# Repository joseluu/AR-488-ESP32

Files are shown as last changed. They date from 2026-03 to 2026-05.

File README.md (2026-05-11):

# MCP-AR-488-ESP32

## Intro and goal

The idea is to have AI help me build electronics. AI needs eyes, the eyes are the oscilloscope which is used through an MCP interface.

The IEEE-488 controler is meant to expose an HTTP API which in turn is used by the MCP server.

## Build

GPIB/IEEE-488 interface board for the **Tektronix TDS784A** oscilloscope, based on an ESP32 (Heltec WiFi Kit 32) with GPIB bus transceivers. The board plugs directly onto the instrument's Centronics 24-pin GPIB connector.

This project is inspired by the [AR-488](https://github.com/Twilight-Logic/AR488) Arduino GPIB adapter, redesigned around the ESP32 for WiFi capability and higher throughput. There are ESP32 projects, such as: https://github.com/douardda/AR488-ESP32 I discovered them after having finished this one. Other projects are using the prologic serial protocol, their hardware most likely may be reflashed with the firmware here.

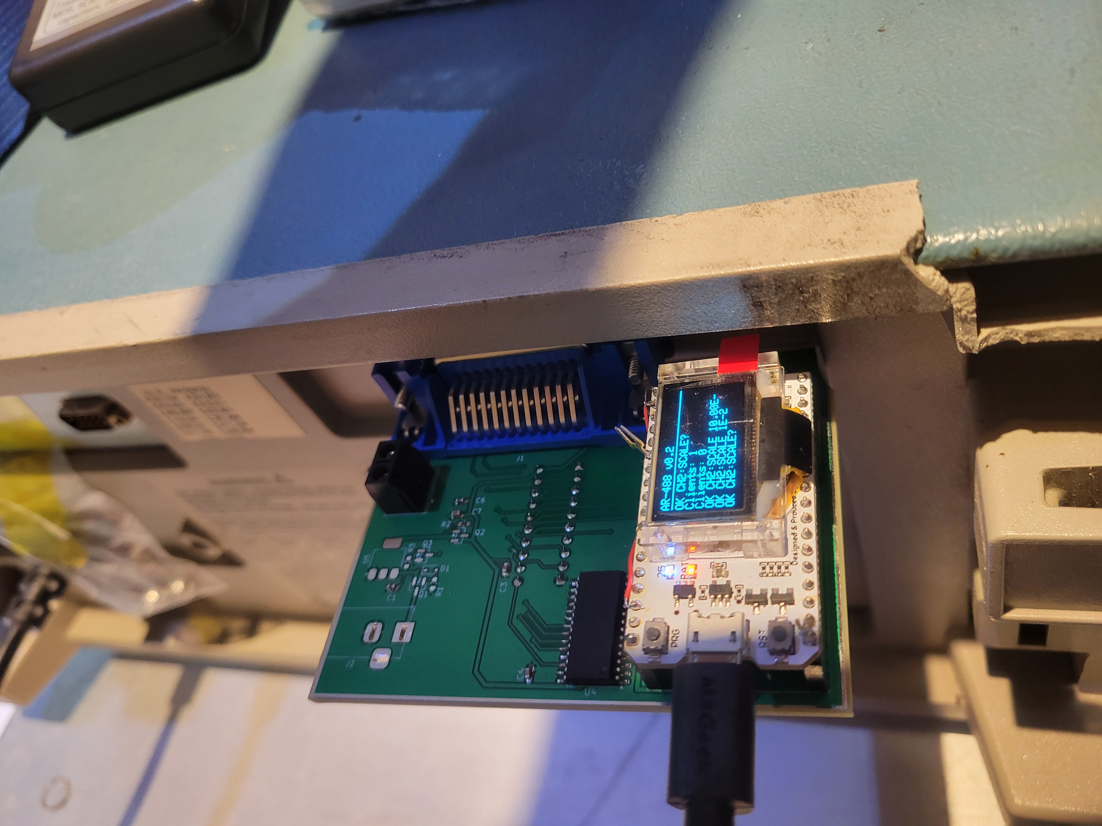
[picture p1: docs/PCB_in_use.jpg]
In use on a 784


There are a few quirks, however the PCB works, requiring some modifications (soldering):
* to supply 3.3V instead of 5.0 V to the MCP chip (because I used a V1 ESP32 board and I thought I had V2)
* add the I2C pullups
* remove 3mm from the left side to fit directly behind the TDS784
If you consider making it check the photos in the docs subdirectory. The gerber files I have used are in AR488_ESP32/Elecrow_manufacturing_v1.1.zip

The ESP32 USB can power the whole board, if you use it this way, no need to populate the barrel jack connector and power supply conditioning part (it has not been tested)

See file [IMPROVEMENTS_V2.md](IMPROVEMENTS_V2.md) for further improvements (which I may never implement myself)

## Design workflow and caveats

The PCB has been designed using AI as well, where claude is driving circuit-synth which in turn generates the kicad schematic. Routing has been handled manually.

Circuit-synth required a modification to work under Windows and git-bash (see my circuit-synth repo). Another circuit-synth
anoyance is that circuit-synth used hierachical connectors on the same sheet, this was giving warnings in the kicad rules checker.

When refreshing the circuit with circuitsynth, it uses a set of new internal identifiers, so when updating the PCB from the electrical schematic (F8) you must check the option "Re-link footprint ... from reference designators"

See file [AI_Assisted_design_workflow.md](AI_Assisted_design_workflow.md)

## Electrical architecture and implementation

See file [Electrical_Architecture.md](Electrical_Architecture.md)

The ESP32 board used is the Heltec Wifi Kit 32 (version 1), the V2 has the same pinout and can be used directly, however the V3 has different I2C pins and most likely will require adjustments to schematic and firmware.

The exposed plated area around is meant for to solder a shield to limit radiated EMI in the lab. Not tested. Shielding completely will also shield the Wifi, so at this point this is a half baked idea.

## Firmware and Software

### Hardware test
In directory hardware_test, a test firmware is available, it sends a 1ms pulse to each of the GPIB connector pins.

### Firmware
The firmware for the ESP32 implements an HTTP API json style server made available on Wifi, not the usual serial protocol.

### Host software
In firmware/test the send_gpib.py allows to exercise many features and get back entire curve data, notably in .csv format, example commands:
```
# getting curve data
uv run --with websockets python firmware/test/send_gpib.py --waveform --points 5000 --out csv --name wave --source CH2 192.168.xx.yy
# getting a screen copy in .tif format
uv run --with websockets python firmware/test/send_gpib.py 192.168.11.175 --hardcopy
```
#### downloaded CSV scope curve example
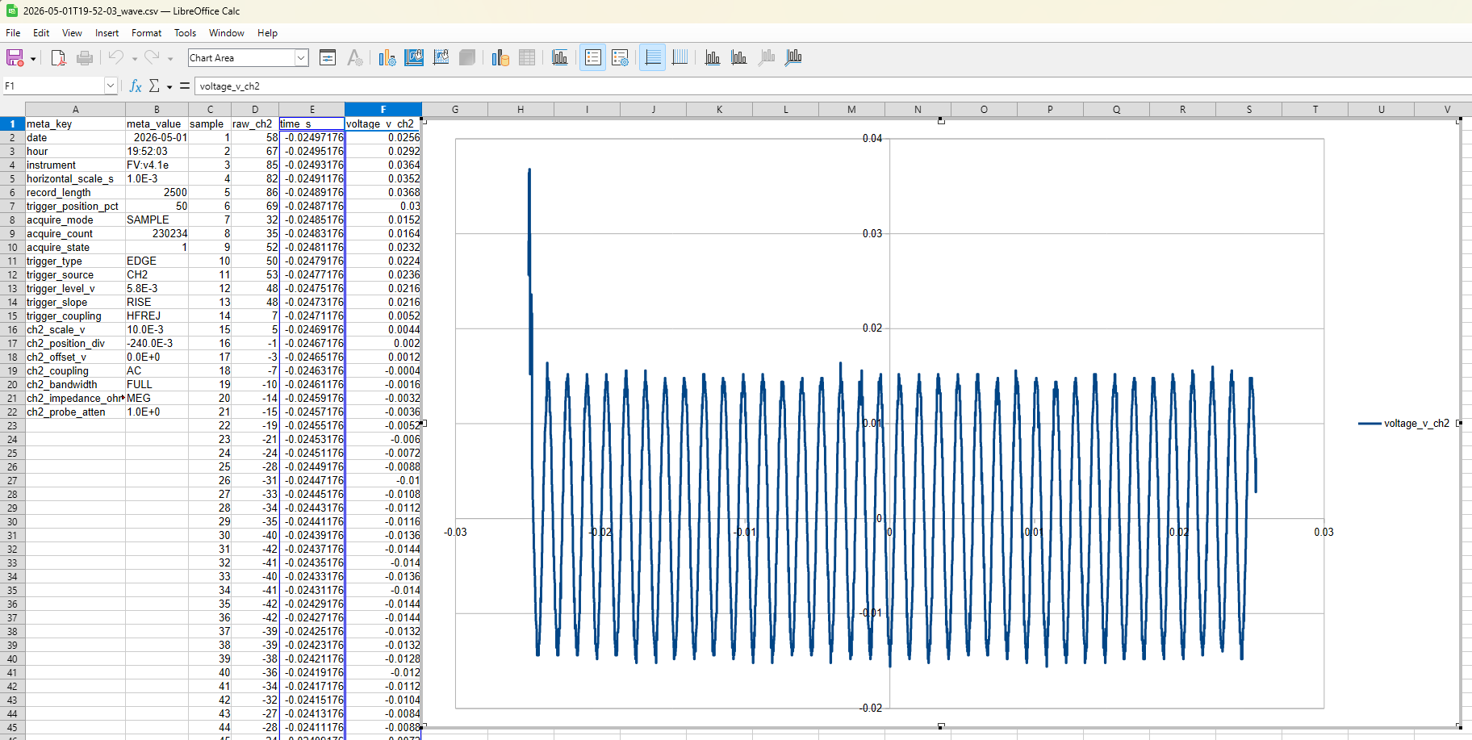
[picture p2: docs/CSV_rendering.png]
CSV being used in LibreOfficeCalc

#### Screen copy through GPIB and host software send_gpib.py
Screen copy through GPIB
#### Actual screen for comparison
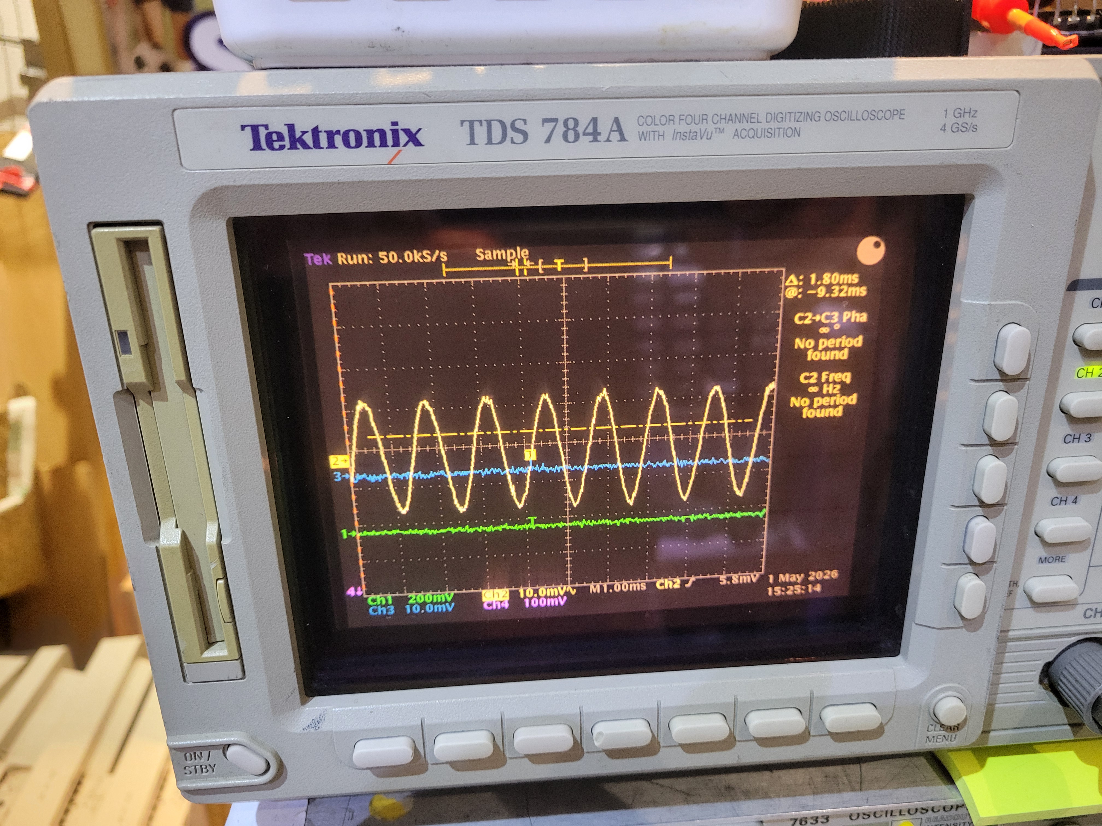
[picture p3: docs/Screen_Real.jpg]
Actual Screen


#### Host software help (-h)
```
send_gpib.py -h
usage: send_gpib.py [-h] [--addr ADDR] [--timeout TIMEOUT] [--binary] [--waveform] [--hardcopy]
                    [--hardcopy-format {TIFF,BMP,BMPCOLOR,PCX,PCXCOLOR,RLE}] [--hardcopy-layout {PORTRAIT,LANDSCAPE}]
                    [--hardcopy-palette {COLOR,MONOCHROME,INKSAVER,HARDCOPY}] [--points POINTS] [--start-index START_INDEX]
                    [--end-index END_INDEX] [--chunk-bytes CHUNK_BYTES] [--source SOURCE] [--width {1,2}] [--name NAME] [--out OUT]
                    host [command]

Send GPIB SCPI commands to a Tek scope via the AR-488-ESP32 gateway.

The ESP32 hosts a JSON-over-WebSocket bridge at ws://<host>/ws. This
script handles the protocol so an operator (or AI agent) can issue
SCPI commands and capture waveforms directly from the shell.

Invocation
----------
    send_gpib.py <ip> <scpi-command>           # auto: query if '?' else write
    send_gpib.py <ip> --binary "<scpi>"        # force binary response
    send_gpib.py <ip> --waveform [options]     # capture waveform(s)
    send_gpib.py <ip> --hardcopy [options]     # capture screen (TIFF default)
    send_gpib.py --help                         # full per-flag help

Output files
------------
Named  <ISO_8601>_<name>[_<chN>].<ext>  where:
  ISO_8601 = YYYY-MM-DDTHH-MM-SS taken at capture start (Windows-safe)
  name     = --name (default 'waveform')
  ext      = controlled by --out: 'csv', 'bin', or 'csv,bin'
  Default for --waveform is csv; other commands write nothing unless
  --out bin is given.

CSV layout
----------
    meta_key, meta_value, sample, raw_chN..., time_s, voltage_v_chN...
- Cols 1-2 hold scope state: date, hour, *IDN?, horizontal/trigger
  setup, then per-channel scale/offset/coupling/etc. Failed queries
  are silently dropped from this block.
- 'sample' is the 1-based scope record index.
- time_s/voltage_v_* are present only when WFMPRE? succeeds.

Windowed / large captures
-------------------------
TDS784A supports up to 500 000 points per record (option 1M). Use
--start-index/--end-index (1-based inclusive) to crop in the
instrument via DATA:START / DATA:STOP - only the requested range
crosses the GPIB bus. Windows larger than --chunk-bytes (default
32 KiB) are chunked transparently to fit the gateway's 64 KiB buffer.

Examples
--------
    send_gpib.py 192.168.1.42 "*IDN?"
    send_gpib.py 192.168.1.42 "CH2:SCALE 500E-3"             # 500 mV/div
    send_gpib.py 192.168.1.42 "HORIZONTAL:MAIN:SCALE?"

    # Default 5 K-pt capture from CH1 -> <stamp>_waveform.csv
    send_gpib.py 192.168.1.42 --waveform

    # Two channels, both CSV and per-channel .bin
    send_gpib.py 192.168.1.42 --waveform --source CH1,CH2 --out csv,bin

    # Full 500 K-pt record at 16-bit, custom name
    send_gpib.py 192.168.1.42 --waveform --points 500000 --width 2 --name run42

    # Sub-window 100k..105k from a 500 K record (5 K samples on the wire)
    send_gpib.py 192.168.1.42 --waveform --points 500000 \
                 --start-index 100000 --end-index 105000

    # Screen hardcopy as TIFF -> <stamp>_screen.tif
    send_gpib.py 192.168.1.42 --hardcopy

    # Hardcopy as BMP color, custom name
    send_gpib.py 192.168.1.42 --hardcopy --hardcopy-format BMPCOLOR --name run42

    # Different scope GPIB address
    send_gpib.py 192.168.1.42 --addr 5 "*IDN?"

positional arguments:
  host                  AR-488-ESP32 IP or hostname (shown on the OLED)
  command               SCPI command (omit when using --waveform)

options:
  -h, --help            show this help message and exit
  --addr ADDR           GPIB primary address (default 1)
  --timeout TIMEOUT     GPIB timeout in ms
  --binary              Force binary_query action (response returned as raw bytes)
  --waveform            Capture a waveform: configures DATA:* and runs CURVE? per channel
  --hardcopy            Capture the scope screen as an image (default TIFF). Saved to <stamp>_<name>.<ext>.
  --hardcopy-format {TIFF,BMP,BMPCOLOR,PCX,PCXCOLOR,RLE}
                        HARDCOPY:FORMAT value (default TIFF)
  --hardcopy-layout {PORTRAIT,LANDSCAPE}
                        HARDCOPY:LAYOUT value (default PORTRAIT)
  --hardcopy-palette {COLOR,MONOCHROME,INKSAVER,HARDCOPY}
                        HARDCOPY:PALETTE value (default COLOR)
  --points POINTS       Default end-index when --end-index is not given (default 5000). Set to the scope's full record length (up
                        to 500000) to grab everything.
  --start-index START_INDEX
                        First record sample to transfer, 1-based (default 1). Maps to DATA:START.
  --end-index END_INDEX
                        Last record sample to transfer, 1-based inclusive (default --points). Maps to DATA:STOP.
  --chunk-bytes CHUNK_BYTES
                        Max bytes per CURVE? response; larger windows are split into chunks transparently (default 32768; the
                        gateway caps at ~64KiB).
  --source SOURCE       Source channel(s), comma-separated (default CH1, e.g. CH1,CH2)
  --width {1,2}         Bytes per sample, 1 or 2 (default 1)
  --name NAME           Stem for output files (default 'waveform' for --waveform, 'screen' for --hardcopy, 'capture' otherwise)
  --out OUT             Output formats, comma-separated: csv, bin. Default for --waveform is 'csv'; for other commands no file is
                        written.
```

## License

MIT

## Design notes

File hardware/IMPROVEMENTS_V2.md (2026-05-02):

# Hardware Improvements & Known Issues (TODO)

This document tracks identified hardware risks and recommended revisions for the **AR-488-ESP32** project to ensure reliable operation with high-performance laboratory equipment like the **Tektronix TDS 784**.

## 0. Priority
* add pull-ups to the I2C lines !
* reduce board with by 5mm on the left side (the larger one) to fit behind the instrument

## 1. nice to have
* MCP supply must be 3.3V, the current design is for a Heltec Wifi Kit 32 (V2) try to find a design compatible with other versions
* map GPIO 5 to a test pin onboard
* Add an I2S microphone to be able to transmit voice commands to the AI
* Add a ground testing pin
* increase pin hole diameter by 0.1mm for the 488 connector pins
* The edge on the GPIB plug side can be shaved back 3mm
* Add test points on the back side, pin 24 ground and pin 1 data

## 2. Possible improvements
The following where found discussing with the AI, must be double checked before implementation

### 2.1 Logic Level Protection (Current Limiting)
* **Issue:** The SN7516x transceivers are 5V TTL devices. Their logic "High" output ($V_{OH}$) can exceed 3.6V, which is the absolute maximum rating for the ESP32 GPIOs.
* **Action:** Add **330Ω series resistors** between every ESP32 GPIO and its corresponding SN7516x pin. This protects the ESP32 from overvoltage and limits current through internal ESD protection diodes.

### 2.2 Boot Strapping Pin Conflicts
The ESP32 samples specific pins at power-up to determine its boot mode. If the GPIB bus is active, it can "back-drive" these pins and prevent the ESP32 from starting (note: this is theoretical, the ESP32 boots well when connected to the instrument)
* **GPIO 12 (MTDI):** Must be **LOW** at boot for 3.3V Flash voltage. If High, the ESP32 will boot-loop.
* **GPIO 2:** Must be **LOW** or floating at boot.
* **GPIO 0:** Must be **HIGH** for normal execution (currently safe via pull-up/button).
* **Fix:** Ensure the SN7516x **Enable (EN)** or **Direction (TE/DC)** pins are pulled to a state that keeps the transceiver in **High-Impedance (High-Z)** mode during power-on.

### 2.3 JTAG / ESP-PROG Compatibility assuming one wants to also have JTAG debugging capability
* **Issue:** The project currently utilizes **GPIO 12, 13, 14, and 15**. These are reserved for the JTAG interface used by the ESP-PROG debugger.
* **Impact:** Real-time hardware debugging is currently impossible while the GPIB interface is connected.
* **Action:** For Revision 2, consider remapping GPIB signals to non-JTAG pins, use GPIO 17, 18, 19, 23, 25, 26, 27, 2 in order to free pins for JTAG

### 2.4 Power & Decoupling
* **Action:** Tie the **GPIB Shield (Pin 12)** to the PCB digital ground to improve signal integrity during high-speed waveform transfers from the TDS 784.

### 2.5 Software-Side Initialization
* **Action:** The firmware `setup()` function must immediately set the Transceiver Control pins (TE/DC) to a "Listen" or "High-Z" state to release the strapping pins as quickly as possible after power-up.

### 2.6 Default-Safe State for SN75161B Direction Inputs
* **Issue:** `TE_CTRL` and `DC` on the SN75161B are driven by the MCP23017. After power-on reset (or any time the MCP23017 is reset or its pins are configured as inputs), the MCP23017 outputs go high-Z and these SN75161B inputs float, leaving the transceiver direction undefined and potentially driving the GPIB bus while the ESP32 is still booting.
* **Action:** Add external pull resistors (10 kΩ) on `TE_CTRL` and `DC` to define a safe default direction (Listen / device) that keeps the bus side high-Z until firmware takes over. With those pulls in place, deliberately tri-stating the MCP outputs (set `IODIRA` bits to 1) becomes a safe "release the bus" operation.

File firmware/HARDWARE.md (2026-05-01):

# AR-488-ESP32 — hardware notes for firmware developers

This document targets a developer (human or AI) porting AR-488 firmware
from another hardware platform to this board. It covers the pieces that
aren't obvious from a stock AR-488 port and that have already cost
debugging time on this design. Chip pinouts, KiCad metadata, and high
level design rationale live in `docs/TECHNICAL_INFORMATIONS.md` — read
that first if you need the chip-level reference.

## At a glance

- **MCU:** Heltec WiFi Kit 32 (ESP32). Two physical revisions exist on
  this board:
  - **V1** — ESP32-D0WDQ6, 26 MHz crystal. PIO env: `heltec_wifi_kit_32`.
  - **V2** — ESP32-PICO-D4, 40 MHz crystal. PIO env:
    `heltec_wifi_kit_32_v2`.
  Both are pin-compatible. Selecting the wrong env produces garbled
  serial because of the wrong crystal divisor.
- **GPIB transceivers:** SN75160B (data, SOIC-20W) + SN75161B (control,
  DIP-20). Both 5 V parts. Direct 3.3 V drive from ESP32 — no level
  shifters. Inputs are TTL (V_IH ~1.5 V), outputs swing 0–5 V on the MCU
  side; the ESP32's input clamp diodes tolerate this in practice but a
  series resistor (~330 Ω) is the safe-by-design fix and is on the
  hardware to-do list.
- **GPIO expander:** MCP23017 at I²C 0x20 (A0=A1=A2=GND, ~RESET tied to
  3.3 V). Powered at 3.3 V to match ESP32 logic levels on SDA/SCL.
- **OLED:** SSD1306 128×64 on internal I²C (GPIO4=SDA, GPIO15=SCL,
  GPIO16=RST). Separate from the GPIB I²C bus. Free for firmware to use
  as a status display.
- **Power:** USB Vbus (5 V) **or** barrel jack 7–12 V → AO4407A reverse
  polarity P-FET → AMS1117-5.0 LDO → 5 V rail. ESP32 module's onboard
  AMS1117-3.3 generates 3.3 V.

## GPIB signal → pin map

This is the canonical mapping. Use it verbatim; deviating breaks the PCB.

### Direct ESP32 GPIOs (data + handshake + EOI + TE_DATA + I²C)

| GPIB signal | ESP32 GPIO | Notes |
|---|---:|---|
| DIO1 | 13 | |
| DIO2 | 12 | **Strapping pin — must be LOW at boot.** |
| DIO3 | 14 | |
| DIO4 | 27 | |
| DIO5 | 26 | |
| DIO6 | 25 | Heltec onboard LED is also wired here. |
| DIO7 | 33 | |
| DIO8 | 32 | |
| DAV | 5 | Strapping pin (must be HIGH at boot — not a problem in practice, see below). |
| NRFD | 18 | |
| NDAC | 23 | |
| EOI | 19 | |
| TE_DATA | 17 | SN75160B Talk Enable. |
| I²C SDA | 21 | To MCP23017 + external pull-up. |
| I²C SCL | 22 | To MCP23017 + external pull-up. |

### MCP23017 GPIOA (slow management path)

| GPIB / control signal | MCP bit (port A) | Drives |
|---|---:|---|
| ATN | 0 | SN75161B ATN terminal pin |
| IFC | 1 | SN75161B IFC terminal pin |
| SRQ | 2 | SN75161B SRQ terminal pin |
| REN | 3 | SN75161B REN terminal pin |
| TE_CTRL | 4 | SN75161B Talk Enable |
| DC | 5 | SN75161B Direction Control |

GPIOB is unused on the board. The test firmware sets it as outputs
forced LOW; do the same to avoid floating CMOS inputs and the
shoot-through current that comes with them.

## Boot-strap caveats — read before writing `setup()`

The ESP32 samples several GPIOs at the rising edge of EN. If the GPIB
bus or the SN7516x outputs back-drive these pins to the wrong level the
chip won't boot.

| GPIO | Strapping role | This board's signal | Required at boot |
|---|---|---|---|
| 0 | Boot mode (HIGH = run) | (unused — boot button) | HIGH |
| 2 | Boot mode | (unused) | LOW or float |
| 5 | VSPI CS bootstrap | DAV | HIGH |
| 12 | Flash voltage (LOW = 3.3 V) | **DIO2** | **LOW (critical)** |
| 15 | Silent boot | (OLED, internal) | (handled by module) |

**What firmware must do at the very top of `setup()` — before anything
else, including `Serial.begin()`:**

1. `pinMode(12, OUTPUT); digitalWrite(12, LOW);` — get DIO2 off the
   strapping value path before the SN75160B has a chance to drive it.
2. Set TE_DATA (GPIO17) to a defined output. Until you do, the ESP32
   pin floats and the SN75160B's MCU-side D pins read whatever the bus
   side is doing. With TE_DATA floating-but-likely-HIGH (SN75160B Talk),
   any bus traffic ends up on the ESP32 D pins — including GPIO12.
3. Initialise I²C and write `IODIRA = 0`, then `OLATA` with TE_CTRL HIGH
   and DC LOW (controller / Talk). Until then the SN75161B's MCU-side
   pins are similarly indeterminate.

GPIO5 (DAV) being a strapping pin worked out in our favour: GPIB DAV is
unasserted = HIGH at idle, which is also the strapping requirement.
Don't drive DAV LOW before the ESP32 finishes booting.

GPIOs 6–11 are tied to internal flash and **must not** be used.
GPIOs 34–39 are input-only and unsuitable for any GPIB signal.

## Hybrid GPIO architecture — what it implies for firmware

This board is **not** a flat-GPIO design like the original AR-488 on
ATmega328P or the 32u4 fork. The 16-bit data + handshake bus is on
direct ESP32 GPIOs (per-cycle latency ~ tens of ns), but the four
management signals (ATN, IFC, SRQ, REN) and the two transceiver control
signals (TE_CTRL, DC) sit behind an I²C link to the MCP23017.

At 400 kHz I²C, one OLATA register write costs roughly **75 µs**
(start + addr + reg + data + stop). At 100 kHz it's roughly four times
that. **Do not put MCP23017 writes inside the per-byte handshake
loop** — only the direct GPIOs (DAV, NRFD, NDAC, DIO1..8, EOI) belong
there. ATN/IFC/REN flip at command boundaries, not data boundaries.

Implementation hints:

- **Cache the OLATA byte in RAM** and do a single-byte write per change
  — the test firmware shows the pattern (`g_mcpOlatA`,
  `mcpSetBitA()`).
- **Don't read-modify-write across boundaries** by doing a separate I²C
  read of GPIOA — the cached copy is authoritative because nothing else
  drives port A.
- For SRQ polling (where the board is in *device* mode and reads SRQ as
  an input), point IODIRA bit 2 to input first, read GPIOA, then put it
  back to output. Polling rate is bounded by 2× the I²C latency.

## Transceiver direction control — getting it right

The SN75161B has *two* direction inputs that decode per signal-group:

| TE  | DC  | DAV | NRFD/NDAC | EOI | ATN/IFC/REN | SRQ |
|-----|-----|---|---|---|---|---|
| 1 | 0 | drive→bus | bus→drive | drive→bus | drive→bus  | bus→drive |
| 0 | 0 | bus→drive | drive→bus | bus→drive | drive→bus  | bus→drive |
| 1 | 1 | drive→bus | bus→drive | drive→bus | bus→drive  | drive→bus |
| 0 | 1 | bus→drive | drive→bus | bus→drive | bus→drive  | drive→bus |

(See SN75161B datasheet table 1 for the authoritative version.)

In practical firmware terms:

- **DC = 0** — controller mode. ATN/IFC/REN are outputs, SRQ is an
  input. Use this for the AR-488 controller-in-charge role.
- **DC = 1** — device mode. ATN/IFC/REN are inputs, SRQ is an output.
  Use this whenever the board is acting as a GPIB device (e.g.
  asserting SRQ to request service).
- **TE = 1** — Talk for the handshake group: DAV is an output, NRFD
  and NDAC are inputs. EOI is also an output.
- **TE = 0** — Listen: DAV is an input, NRFD and NDAC are outputs.
  EOI is an input.

**Lesson learned from bring-up (don't re-derive it):**

While bringing the board up we tried flipping TE_CTRL on a per-pulse
basis to get a particular signal driven outward. Doing so produces
**coupling artefacts on neighbouring lines** — ghost edges on signals
that share the direction-decode group inside the SN75161B. The robust
pattern is:

1. Choose the bus role for the operation (controller or device).
2. Choose the direction (Talk or Listen).
3. Set TE_CTRL and DC accordingly **once** at the boundary, settle (a
   few µs is enough; the test firmware uses 1 ms as a generous margin).
4. Run the whole transaction with TE_CTRL fixed.

DC may legitimately need to flip mid-sequence (e.g. asserting SRQ as a
device while the rest of the board is in controller mode). That's fine
— it's the per-pulse TE flips that misbehave.

TE_DATA on the SN75160B is independent and only affects DIO1..8. Flip
it freely with the bus direction; there's no internal coupling between
DIO bits.

## Logic polarity (easy to get wrong)

The SN7516x parts are **non-inverting** between MCU and bus. The GPIB
bus itself is **negative-true** (a signal is *asserted* when the bus
line is LOW, due to its open-collector / wired-or nature).

Combined: writing **0** to a Talk-direction MCU pin asserts the
corresponding GPIB signal; writing **1** unasserts it. Same on the
input side — reading **0** from a Listen-direction MCU pin means the
bus signal is asserted.

The pin-test firmware (`firmware/test/`) pulses signals **HIGH** for
visibility on a scope; that's the *unasserted* level on the bus. Real
firmware should treat HIGH as the idle / negated state and assert by
driving LOW.

## I²C bus details

- **Pins:** SDA = GPIO21, SCL = GPIO22.
- **External pull-ups required.** ESP32 internal pulls (~45 kΩ) are
  too weak for reliable 400 kHz operation across PCB traces. Without
  proper pull-ups the new ESP-IDF i2c_master_ng driver returns
  `ESP_ERR_INVALID_STATE` on writes (it presents as "MCP not
  responding").
- **Speed:** 400 kHz works; 1 MHz is in the MCP23017's spec but
  hasn't been tested on this board.
- **Address:** MCP23017 at 0x20. Nothing else on this bus by default.

The internal SSD1306 OLED on the ESP32 module sits on a *different*
I²C bus (GPIO4/GPIO15) and does not interfere.

## Power notes

- USB Vbus and the barrel jack are diode-OR'd at the 5 V rail (P-FET
  reverse-polarity protection on the jack side). It's safe to have
  both connected; whichever is higher wins.
- The 3.3 V rail is generated by the Heltec module's own LDO from the
  5 V rail. Current budget for 3.3 V peripherals is small — don't add
  loads of more than ~100 mA on 3.3 V without checking.
- Decoupling: 100 nF + 22 µF on each transceiver, 100 nF on the
  MCP23017. Already on the PCB; mentioned for context if you're
  measuring noise.

## Reference firmware

The likely starting point for adaptation is the upstream AR-488:

- **Original (ATmega328P / Arduino Uno R3):**
  https://github.com/Twilight-Logic/AR488
- **32u4 fork:**
  https://github.com/artgodwin/AR488-32u4-PCB

Things in those codebases that **will not survive the port** unchanged:

- Direct port-register writes (`PORTB`, `PORTD`, `PINx`) — replace
  with `digitalWrite()` / `digitalRead()` or with ESP32's
  `GPIO.out_w1ts` / `out_w1tc` registers if you need the speed.
- Timing assumed at 16 MHz — recalibrate for 240 MHz ESP32.
- Single-port assumption (all GPIB signals on one MCU port) — not
  true here; the management signals are behind I²C.
- Pin-change interrupts — ESP32 supports them per-GPIO, not
  per-port.
- AVR sleep modes — different on ESP32; usually irrelevant for an
  always-on bus interface anyway.

A clean structural split for the port is to keep AR-488's command
parser and SCPI logic intact and replace only the bus-driver layer
with one that knows about the direct/MCP split.

## Per-pin verification

`firmware/test/` contains a stand-alone sketch that pulses every GPIB
signal in connector pin-number order. Use it to confirm the wiring
end-to-end (GPIO → transceiver → connector pin) before bringing up the
real firmware. See `firmware/test/README.md` for what it does and the
direction-control choices it embeds.

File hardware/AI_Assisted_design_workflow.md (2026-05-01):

## Design workflow with claude _ circuitsynth and kicad

The schematic is written in Python using [circuit-synth](https://github.com/circuit-synth/circuit-synth), which generates KiCad 9/10 project files. The PCB layout is done in KiCad, assisted by AI through the IPC API.

```mermaid
flowchart TD
    A["circuit-synth/main.py\nPython circuit description"] --> B["circuit-synth\nGenerates .kicad_sch, .kicad_pro, netlist"]
    B --> C["KiCad schematic editor\nReview, ERC"]
    C --> D["KiCad PCB editor\nImport netlist, place components manually"]
    D --> E["FreeRouting\nAutoroute bulk signals"]
    E --> F["AI via IPC API (MCP server)\nRefine routing, ground plane, DRC review"]
    F --> G["Final review + Gerbers\nManufacturing files"]
```

### Generating the schematic

```bash
export KICAD_SYMBOL_DIR="C:/Program Files/KiCad/9.0/share/kicad/symbols;$(pwd)/libs"
export PYTHONIOENCODING=utf-8
uv run python circuit-synth/main.py
```

The generated KiCad project is in `AR488_ESP32/`.

## Development environment setup

### Prerequisites

- **OS:** Windows 11 under **Git Bash** (Unix shell syntax throughout)
- **Python:** 3.12 via [uv](https://github.com/astral-sh/uv)
- **KiCad:** 9.0 (or 10.0 — the IPC API is the same)
- **FreeRouting:** installed as KiCad plugin or [standalone](https://github.com/freerouting/freerouting)

### Installing circuit-synth

circuit-synth is included as a **git submodule** pointing to `joseluu/circuit-synth` on the `fix/windows-utf8-file-write` branch. This branch contains fixes for Windows UTF-8 encoding issues (emoji in logs, missing `encoding="utf-8"` on `write_text()` calls) that are not yet merged upstream.

```bash
# Clone with submodule
git clone --recurse-submodules <this-repo-url>
cd AR-488-ESP32

# Or if already cloned without submodules
git submodule update --init

# Create the virtual environment and install circuit-synth in editable mode
uv sync
```

The `pyproject.toml` references circuit-synth as a local editable dependency:

```toml
[tool.uv.sources]
circuit-synth = { path = "circuit-synth", editable = true }
```

If the upstream UTF-8 fixes are eventually merged into `circuit-synth/circuit-synth`, you can switch the submodule to track the official repo instead.

### Custom KiCad libraries

The `libs/` directory contains project-specific symbols and footprints:

- `AR488_custom.kicad_sym` — SN75161BN (not in KiCad standard library), AO4407A P-FET
- `AR488_custom.pretty/Centronics_24_GPIB.kicad_mod` — Centronics 24-pin plug (2x12, 2.159mm pitch, 4.45mm row spacing, top-bottom pin numbering)
- `AR488_custom.pretty/Heltec_WiFi_Kit_32_V2.kicad_mod` — ESP32 module header (2x18, 22.86mm row spacing)

These are referenced via `KICAD_SYMBOL_DIR` at generation time (see above).

## AI-assisted PCB routing (Option C)

The PCB layout is refined using Claude via KiCad's IPC API and the Model Context Protocol (MCP).

### Setting up the MCP server

1. **Enable IPC API in KiCad:** Preferences > Plugins > Enable IPC API Server

2. **Install the MCP server** — we use [mixelpixx/KiCAD-MCP-Server](https://github.com/mixelpixx/KiCAD-MCP-Server) (Node.js + Python):

   ```bash
   # Clone next to this project
   cd ..
   git clone https://github.com/mixelpixx/KiCAD-MCP-Server.git
   cd KiCAD-MCP-Server

   # Install Node.js dependencies and build (requires Node.js 18+)
   npm install          # also runs tsc via postinstall

   # Install Python dependencies into KiCad's bundled Python (NOT system Python)
   # KiCad 9 ships its own Python 3.11 — the MCP server must use it because
   # pcbnew.pyd is compiled for that specific interpreter.
   "/c/Program Files/KiCad/9.0/bin/python.exe" -m pip install -r requirements.txt
   ```

3. **Install the IPC backend** (optional but recommended for real-time UI sync):

   ```bash
   # Install kicad-python (provides kipy — Protocol Buffers + NNG transport)
   "/c/Program Files/KiCad/9.0/bin/python.exe" -m pip install kicad-python
   ```

   The MCP server auto-detects the backend at startup:
   - **IPC backend** (`kipy` installed + KiCad running with IPC enabled): real-time UI sync, read operations work live. Write operations (routing) currently fall back to SWIG.
   - **SWIG backend** (fallback): reads/writes `.kicad_pcb` directly. Requires File > Revert in KiCad to see changes.

   SWIG is deprecated in KiCad 9 and will be removed in KiCad 10. The IPC write path is under active development.

4. **Configure Claude Code** — create a `.mcp.json` file in the **AR-488-ESP32 project directory** (already checked into the repo):

   ```json
   {
     "mcpServers": {
       "kicad": {
         "command": "<full-path-to-node>",
         "args": ["<path-to>/KiCAD-MCP-Server/dist/index.js"],
         "env": {
           "KICAD_PROJECT_DIR": "<path-to>/AR-488-ESP32/AR488_ESP32",
           "KICAD_PYTHON": "C:/Program Files/KiCad/9.0/bin/python.exe"
         }
       }
     }
   }
   ```

   Key points:
   - Use the **full path to node** (nvm-managed node isn't on PATH for spawned processes)
   - `KICAD_PYTHON` tells the server to use KiCad's bundled Python (required for pcbnew access)
   - Claude Code detects `.mcp.json` automatically when launched from the project directory

5. **Workflow:**
   - Open the PCB in KiCad's PCB editor
   - Enable IPC API: Preferences > Plugins > Enable IPC API Server
   - Place components manually (connector at board edge, decoupling caps near their ICs)
   - Manually route critical traces (power rails, high-speed signals)
   - Run FreeRouting to autoroute remaining signals (install via Plugin and Content Manager)
   - Use Claude via MCP to review DRC, optimize trace widths, add ground plane, adjust silkscreen
   - After SWIG writes: File > Revert to see changes in KiCad

### Current limitations

- The IPC API only supports the **PCB editor** (pcbnew). There is no schematic API yet — that's why we generate `.kicad_sch` files directly with circuit-synth.
- The mixelpixx MCP server uses IPC for read operations but falls back to SWIG for writes (routing, component placement). After SWIG writes, you must File > Revert in KiCad.
- Headless mode (kicad-cli as IPC server) is planned but not yet implemented.
- SWIG is deprecated in KiCad 9 and will be removed in KiCad 10 — plan to migrate to full IPC.
- Alternative: [Finerestaurant/kicad-mcp-python](https://github.com/Finerestaurant/kicad-mcp-python) is IPC-only (no SWIG) but still v0.1.

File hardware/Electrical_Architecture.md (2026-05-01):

## Electrical architecture

### Block diagram

```mermaid
flowchart TD
    PSU["7-12V DC\nBarrel Jack J2"] --> Q1["Q1 AO3401A\nP-FET RPP"]
    Q1 --> U5["U5 AMS1117-5.0\nLDO → 5V"]
    Q1 -.- D1["D1 MM3Z8V2\ngate clamp"]

    U5 --> V5[ ]:::hidden
    V5 --> U2["U2 SN75160BDW\nData transceiver\nSOIC-20, 5V"]
    V5 --> U3["U3 SN75161BN\nCtrl transceiver\nDIP-20, 5V"]
    V5 --> U4["U4 MCP23017\nI2C GPIO exp.\nSOIC-28, 3.3V"]

    U2 -- "DIO1-8 (8)\nTE_data (1)" --> U1["U1 Heltec WiFi Kit 32 V2\nESP32"]
    U3 -- "DAV, NRFD, NDAC, EOI (4)\ndirect GPIO" --> U1
    U4 -- "I2C bus\nSDA/SCL" --> U1

    U2 --> J1["J1 Centronics 24-pin\nGPIB connector"]
    U3 --> J1
    J1 --> J3["J3 Shield\nscrew terminal"]

    classDef hidden display:none;
```

### GPIB bus transceivers

The GPIB bus requires 5V signaling. Two TI transceivers handle the voltage translation:

- **SN75160BDW** (U2) — 8-bit bidirectional data bus transceiver (DIO1-DIO8). The `~PE` pin is tied to VCC to disable 3-state mode. Direction is controlled by `TE_data` from ESP32 GPIO17.

- **SN75161BN** (U3) — Control bus transceiver handling DAV, NRFD, NDAC, EOI, ATN, IFC, SRQ, REN. Direction is controlled by `TE_ctrl` and `DC`, both from the MCP23017.

No level shifters are needed: ESP32 3.3V outputs exceed the SN7516x TTL input threshold (~1.5V VIH).

### External power with reverse polarity protection

The board can be powered from a 7-12V barrel jack (J2) or from USB via the ESP32 module's 5V pin.

The barrel jack path uses an **AO3401A P-channel MOSFET** (Q1, SOT-23) for reverse polarity protection:
- Source connected to barrel jack V+
- Drain connected to AMS1117-5.0 LDO input
- Gate pulled to GND via 100k resistor (R1)
- **D1 MM3Z8V2** Zener diode (SOD-323) clamps the gate-drain voltage for ESD/spike protection

Normal operation: Vgs = 0 - Vin << 0, FET is ON with millivolt drop (~2.4mV at 200mA). Reverse polarity: Vgs >= 0, FET is OFF, circuit protected.

The **AMS1117-5.0** (U5, SOT-223) regulates down to 5V. Capacitors: 10uF input (C1), 10uF output (C2), all 0603.

Another **AO3401A P-channel MOSFET** protects the AMS1117 against current flowing back into it when the board is powered by the ESP32 (via USB)

### I2C GPIO expander — why and how

The Heltec WiFi Kit 32 V2 only exposes 16 bidirectional GPIOs (the OLED uses GPIO4/15/16). GPIB requires 18+ signals. The **MCP23017** (U4, SOIC-28) adds 16 GPIOs via I2C, of which 6 are used for slow management signals.

**Critical design choice:** The MCP23017 is powered at **3.3V**, not 5V. This is because the ESP32 I2C lines output 3.3V, and the MCP23017 at 5V requires VIH = 0.7 x 5V = 3.5V — which 3.3V cannot reliably meet. At 3.3V, the MCP23017's outputs still drive the SN75161B TTL inputs correctly (VIH ~ 1.5V).

I2C address: 0x20 (A0=A1=A2=GND). RESET tied to VCC.

### Signal routing: fast path vs slow path

The signal split between direct GPIOs and the MCP23017 is deliberate:

| Path | Signals | Latency | Used during |
|---|---|---|---|
| **Direct GPIO** (fast) | DIO1-8, DAV, NRFD, NDAC, EOI, TE_data | ~0 ns | Every byte transfer |
| **MCP23017 I2C** (slow) | ATN, IFC, SRQ, REN, TE_ctrl, DC | ~100 us | Bus mode changes only |

**Timing-constrained signals (data + handshake) are never routed through the I2C expander.** The three-wire handshake (DAV/NRFD/NDAC) and data lines (DIO1-8) must respond within microseconds during transfers. ATN, IFC, SRQ, and REN only change during bus management operations (addressing, interface clear, service request) — millisecond-level latency is acceptable.

This hybrid architecture allows the TDS784A's fast GPIB transfers (200-500 KB/s) to run at full speed while fitting within the ESP32's limited GPIO count.

## Component summary

| Ref | Component | Package | Description |
|-----|---|---|---|
| U1 | Heltec WiFi Kit 32 | 2x18 pin header | ESP32 MCU with OLED |
| U2 | SN75160BDW | SOIC-20W | GPIB data bus transceiver |
| U3 | SN75161BN | DIP-20 | GPIB control bus transceiver |
| U4 | MCP23017 | SOIC-28 | I2C GPIO expander |
| U5 | AMS1117-5.0 | SOT-223 | 5V LDO regulator |
| Q1 | AO3401A | SOT-23 | P-FET reverse polarity protection |
| Q2 | AO3401A | SOT-23 | P-FET backflow protection to AMS1117-5.0 |
| Q3 | MMBT55551L | SOT-23 | NPN power sensing |
| D1 | MM3Z8V2 | SOD-323 | 8.2V Zener gate clamp |
| J1 | Centronics 24-pin | Custom | GPIB connector |
| J2 | Barrel jack | Horizontal | 7-12V DC input |
| J3 | Screw terminal 1x2 | Phoenix PT-1.5 5mm | Shield connection |
| R1 | 100k | 0603 | Q1 gate pullup (makes it conductor) |
| R2 | 100k | 0603 | Q2 gate pulldown (makes it block) |
| R3 | 10k  | 0603 | Q3 power sensing base current limiter |
| C1 | 10uF | 0603 | LDO input cap |
| C2 | 10uF | 0603 | LDO output cap |
| C3,C4 | 100nF | 0603 | SN7516x decoupling |
| C5 | 100nF | 0603 | MCP23017 decoupling |
| C6,C7 | 22uF | 0603 | SN7516x bulk bypass |

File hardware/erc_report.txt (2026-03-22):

ERC report (2026-03-22T00:00:25+0100, Encoding UTF8)

***** Sheet /
[pin_not_connected]: Hierarchical label "SDA" in root sheet cannot be connected to non-existent parent sheet
    ; error
    @(27.94 mm, 35.56 mm): Hierarchical Label 'SDA'
[pin_not_connected]: Hierarchical label "SCL" in root sheet cannot be connected to non-existent parent sheet
    ; error
    @(27.94 mm, 38.10 mm): Hierarchical Label 'SCL'
[pin_not_connected]: Pin not connected
    ; error
    @(27.94 mm, 50.80 mm): Symbol U4 Pin 19 [INTB, Tri-state, Line]
[pin_not_connected]: Pin not connected
    ; error
    @(27.94 mm, 53.34 mm): Symbol U4 Pin 20 [INTA, Tri-state, Line]
[pin_not_connected]: Pin not connected
    ; error
    @(63.50 mm, 35.56 mm): Symbol U4 Pin 1 [GPB0, Bidirectional, Line]
[pin_not_connected]: Pin not connected
    ; error
    @(63.50 mm, 38.10 mm): Symbol U4 Pin 2 [GPB1, Bidirectional, Line]
[pin_not_connected]: Pin not connected
    ; error
    @(63.50 mm, 40.64 mm): Symbol U4 Pin 3 [GPB2, Bidirectional, Line]
[pin_not_connected]: Pin not connected
    ; error
    @(63.50 mm, 43.18 mm): Symbol U4 Pin 4 [GPB3, Bidirectional, Line]
[pin_not_connected]: Pin not connected
    ; error
    @(63.50 mm, 45.72 mm): Symbol U4 Pin 5 [GPB4, Bidirectional, Line]
[pin_not_connected]: Pin not connected
    ; error
    @(63.50 mm, 48.26 mm): Symbol U4 Pin 6 [GPB5, Bidirectional, Line]
[pin_not_connected]: Pin not connected
    ; error
    @(63.50 mm, 50.80 mm): Symbol U4 Pin 7 [GPB6, Bidirectional, Line]
[pin_not_connected]: Pin not connected
    ; error
    @(63.50 mm, 53.34 mm): Symbol U4 Pin 8 [GPB7, Output, Line]
[pin_not_connected]: Hierarchical label "ATN" in root sheet cannot be connected to non-existent parent sheet
    ; error
    @(63.50 mm, 58.42 mm): Hierarchical Label 'ATN'
[pin_not_connected]: Hierarchical label "IFC" in root sheet cannot be connected to non-existent parent sheet
    ; error
    @(63.50 mm, 60.96 mm): Hierarchical Label 'IFC'
[pin_not_connected]: Hierarchical label "SRQ" in root sheet cannot be connected to non-existent parent sheet
    ; error
    @(63.50 mm, 63.50 mm): Hierarchical Label 'SRQ'
[pin_not_connected]: Hierarchical label "REN" in root sheet cannot be connected to non-existent parent sheet
    ; error
    @(63.50 mm, 66.04 mm): Hierarchical Label 'REN'
[pin_not_connected]: Hierarchical label "TE_CTRL" in root sheet cannot be connected to non-existent parent sheet
    ; error
    @(86.36 mm, 35.56 mm): Hierarchical Label 'TE_CTRL'
[pin_not_connected]: Hierarchical label "TE_CTRL" in root sheet cannot be connected to non-existent parent sheet
    ; error
    @(86.36 mm, 35.56 mm): Hierarchical Label 'TE_CTRL'
[pin_not_connected]: Hierarchical label "TE_CTRL" in root sheet cannot be connected to non-existent parent sheet
    ; error
    @(63.50 mm, 68.58 mm): Hierarchical Label 'TE_CTRL'
[pin_not_connected]: Hierarchical label "DC" in root sheet cannot be connected to non-existent parent sheet
    ; error
    @(86.36 mm, 38.10 mm): Hierarchical Label 'DC'
[pin_not_connected]: Hierarchical label "DC" in root sheet cannot be connected to non-existent parent sheet
    ; error
    @(86.36 mm, 38.10 mm): Hierarchical Label 'DC'
[pin_not_connected]: Hierarchical label "DC" in root sheet cannot be connected to non-existent parent sheet
    ; error
    @(63.50 mm, 71.12 mm): Hierarchical Label 'DC'
[pin_not_connected]: Hierarchical label "REN" in root sheet cannot be connected to non-existent parent sheet
    ; error
    @(86.36 mm, 43.18 mm): Hierarchical Label 'REN'
[pin_not_connected]: Hierarchical label "REN" in root sheet cannot be connected to non-existent parent sheet
    ; error
    @(86.36 mm, 43.18 mm): Hierarchical Label 'REN'
[pin_not_connected]: Pin not connected
    ; error
    @(63.50 mm, 73.66 mm): Symbol U4 Pin 27 [GPA6, Bidirectional, Line]
[pin_not_connected]: Hierarchical label "IFC" in root sheet cannot be connected to non-existent parent sheet
    ; error
    @(86.36 mm, 45.72 mm): Hierarchical Label 'IFC'
[pin_not_connected]: Hierarchical label "IFC" in root sheet cannot be connected to non-existent parent sheet
    ; error
    @(86.36 mm, 45.72 mm): Hierarchical Label 'IFC'
[pin_not_connected]: Hierarchical label "NDAC" in root sheet cannot be connected to non-existent parent sheet
    ; error
    @(86.36 mm, 48.26 mm): Hierarchical Label 'NDAC'
[pin_not_connected]: Hierarchical label "NDAC" in root sheet cannot be connected to non-existent parent sheet
    ; error
    @(86.36 mm, 48.26 mm): Hierarchical Label 'NDAC'
[pin_not_connected]: Pin not connected
    ; error
    @(63.50 mm, 76.20 mm): Symbol U4 Pin 28 [GPA7, Output, Line]
[pin_not_connected]: Hierarchical label "NRFD" in root sheet cannot be connected to non-existent parent sheet
    ; error
    @(86.36 mm, 50.80 mm): Hierarchical Label 'NRFD'
[pin_not_connected]: Hierarchical label "NRFD" in root sheet cannot be connected to non-existent parent sheet
    ; error
    @(86.36 mm, 50.80 mm): Hierarchical Label 'NRFD'
[pin_not_connected]: Hierarchical label "DAV" in root sheet cannot be connected to non-existent parent sheet
    ; error
    @(86.36 mm, 53.34 mm): Hierarchical Label 'DAV'
[pin_not_connected]: Hierarchical label "DAV" in root sheet cannot be connected to non-existent parent sheet
    ; error
    @(86.36 mm, 53.34 mm): Hierarchical Label 'DAV'
[pin_not_connected]: Hierarchical label "EOI" in root sheet cannot be connected to non-existent parent sheet
    ; error
    @(86.36 mm, 55.88 mm): Hierarchical Label 'EOI'
[pin_not_connected]: Hierarchical label "EOI" in root sheet cannot be connected to non-existent parent sheet
    ; error
    @(86.36 mm, 55.88 mm): Hierarchical Label 'EOI'
[pin_not_connected]: Hierarchical label "ATN" in root sheet cannot be connected to non-existent parent sheet
    ; error
    @(86.36 mm, 58.42 mm): Hierarchical Label 'ATN'
[pin_not_connected]: Hierarchical label "ATN" in root sheet cannot be connected to non-existent parent sheet
    ; error
    @(86.36 mm, 58.42 mm): Hierarchical Label 'ATN'
[pin_not_connected]: Hierarchical label "SRQ" in root sheet cannot be connected to non-existent parent sheet
    ; error
    @(86.36 mm, 60.96 mm): Hierarchical Label 'SRQ'
[pin_not_connected]: Hierarchical label "SRQ" in root sheet cannot be connected to non-existent parent sheet
    ; error
    @(86.36 mm, 60.96 mm): Hierarchical Label 'SRQ'
[pin_not_connected]: Hierarchical label "REN_B" in root sheet cannot be connected to non-existent parent sheet
    ; error
    @(111.76 mm, 43.18 mm): Hierarchical Label 'REN_B'
[pin_not_connected]: Hierarchical label "REN_B" in root sheet cannot be connected to non-existent parent sheet
    ; error
    @(111.76 mm, 43.18 mm): Hierarchical Label 'REN_B'
[pin_not_connected]: Hierarchical label "IFC_B" in root sheet cannot be connected to non-existent parent sheet
    ; error
    @(111.76 mm, 45.72 mm): Hierarchical Label 'IFC_B'
[pin_not_connected]: Hierarchical label "IFC_B" in root sheet cannot be connected to non-existent parent sheet
    ; error
    @(111.76 mm, 45.72 mm): Hierarchical Label 'IFC_B'
[pin_not_connected]: Hierarchical label "NDAC_B" in root sheet cannot be connected to non-existent parent sheet
    ; error
    @(111.76 mm, 48.26 mm): Hierarchical Label 'NDAC_B'
[pin_not_connected]: Hierarchical label "NDAC_B" in root sheet cannot be connected to non-existent parent sheet
    ; error
    @(111.76 mm, 48.26 mm): Hierarchical Label 'NDAC_B'
[pin_not_connected]: Hierarchical label "NRFD_B" in root sheet cannot be connected to non-existent parent sheet
    ; error
    @(111.76 mm, 50.80 mm): Hierarchical Label 'NRFD_B'
[pin_not_connected]: Hierarchical label "NRFD_B" in root sheet cannot be connected to non-existent parent sheet
    ; error
    @(111.76 mm, 50.80 mm): Hierarchical Label 'NRFD_B'
[pin_not_connected]: Hierarchical label "DAV_B" in root sheet cannot be connected to non-existent parent sheet
    ; error
    @(111.76 mm, 53.34 mm): Hierarchical Label 'DAV_B'
[pin_not_connected]: Hierarchical label "DAV_B" in root sheet cannot be connected to non-existent parent sheet
    ; error
    @(111.76 mm, 53.34 mm): Hierarchical Label 'DAV_B'
[pin_not_connected]: Hierarchical label "EOI_B" in root sheet cannot be connected to non-existent parent sheet
    ; error
    @(111.76 mm, 55.88 mm): Hierarchical Label 'EOI_B'
[pin_not_connected]: Hierarchical label "EOI_B" in root sheet cannot be connected to non-existent parent sheet
    ; error
    @(111.76 mm, 55.88 mm): Hierarchical Label 'EOI_B'
[pin_not_connected]: Hierarchical label "ATN_B" in root sheet cannot be connected to non-existent parent sheet
    ; error
    @(111.76 mm, 58.42 mm): Hierarchical Label 'ATN_B'
[pin_not_connected]: Hierarchical label "ATN_B" in root sheet cannot be connected to non-existent parent sheet
    ; error
    @(111.76 mm, 58.42 mm): Hierarchical Label 'ATN_B'
[pin_not_connected]: Hierarchical label "SRQ_B" in root sheet cannot be connected to non-existent parent sheet
    ; error
    @(111.76 mm, 60.96 mm): Hierarchical Label 'SRQ_B'
[pin_not_connected]: Hierarchical label "SRQ_B" in root sheet cannot be connected to non-existent parent sheet
    ; error
    @(111.76 mm, 60.96 mm): Hierarchical Label 'SRQ_B'
[pin_not_connected]: Hierarchical label "LDO_IN" in root sheet cannot be connected to non-existent parent sheet
    ; error
    @(35.56 mm, 134.62 mm): Hierarchical Label 'LDO_IN'
[pin_not_connected]: Hierarchical label "LDO_IN" in root sheet cannot be connected to non-existent parent sheet
    ; error
    @(35.56 mm, 134.62 mm): Hierarchical Label 'LDO_IN'
[pin_not_connected]: Hierarchical label "DIO1" in root sheet cannot be connected to non-existent parent sheet
    ; error
    @(137.16 mm, 35.56 mm): Hierarchical Label 'DIO1'
[pin_not_connected]: Hierarchical label "DIO2" in root sheet cannot be connected to non-existent parent sheet
    ; error
    @(137.16 mm, 38.10 mm): Hierarchical Label 'DIO2'
[pin_not_connected]: Hierarchical label "Q1_GATE" in root sheet cannot be connected to non-existent parent sheet
    ; error
    @(27.94 mm, 139.70 mm): Hierarchical Label 'Q1_GATE'
[pin_not_connected]: Hierarchical label "Q1_GATE" in root sheet cannot be connected to non-existent parent sheet
    ; error
    @(27.94 mm, 139.70 mm): Hierarchical Label 'Q1_GATE'
[pin_not_connected]: Hierarchical label "DIO3" in root sheet cannot be connected to non-existent parent sheet
    ; error
    @(137.16 mm, 40.64 mm): Hierarchical Label 'DIO3'
[pin_not_connected]: Hierarchical label "DIO4" in root sheet cannot be connected to non-existent parent sheet
    ; error
    @(137.16 mm, 43.18 mm): Hierarchical Label 'DIO4'
[pin_not_connected]: Hierarchical label "DIO5" in root sheet cannot be connected to non-existent parent sheet
    ; error
    @(137.16 mm, 45.72 mm): Hierarchical Label 'DIO5'
[pin_not_connected]: Hierarchical label "DIO6" in root sheet cannot be connected to non-existent parent sheet
    ; error
    @(137.16 mm, 48.26 mm): Hierarchical Label 'DIO6'
[pin_not_connected]: Pin not connected
    ; error
    @(71.12 mm, 127.00 mm): Symbol J2 Pin 1 [Passive, Line]
[pin_not_connected]: Hierarchical label "DIO7" in root sheet cannot be connected to non-existent parent sheet
    ; error
    @(137.16 mm, 50.80 mm): Hierarchical Label 'DIO7'
[pin_not_connected]: Hierarchical label "DIO8" in root sheet cannot be connected to non-existent parent sheet
    ; error
    @(137.16 mm, 53.34 mm): Hierarchical Label 'DIO8'
[pin_not_connected]: Pin not connected
    ; error
    @(35.56 mm, 144.78 mm): Symbol Q1 Pin 1 [S, Passive, Line]
[pin_not_connected]: Hierarchical label "DIO1_B" in root sheet cannot be connected to non-existent parent sheet
    ; error
    @(157.48 mm, 35.56 mm): Hierarchical Label 'DIO1_B'
[pin_not_connected]: Hierarchical label "DIO2_B" in root sheet cannot be connected to non-existent parent sheet
    ; error
    @(157.48 mm, 38.10 mm): Hierarchical Label 'DIO2_B'
[pin_not_connected]: Hierarchical label "Q1_GATE" in root sheet cannot be connected to non-existent parent sheet
    ; error
    @(91.44 mm, 135.89 mm): Hierarchical Label 'Q1_GATE'
[pin_not_connected]: Hierarchical label "LDO_IN" in root sheet cannot be connected to non-existent parent sheet
    ; error
    @(116.84 mm, 133.35 mm): Hierarchical Label 'LDO_IN'
[power_pin_not_driven]: Input Power pin not driven by any Output Power pins
    ; error
    @(180.34 mm, 27.94 mm): Symbol #PWR028 Pin 1 [Power input, Line]
[pin_not_connected]: Pin not connected
    ; error
    @(180.34 mm, 30.48 mm): Symbol U1 Pin 5 [Pin_5, Passive, Line]
[pin_not_connected]: Pin not connected
    ; error
    @(180.34 mm, 33.02 mm): Symbol U1 Pin 7 [Pin_7, Passive, Line]
[pin_not_connected]: Hierarchical label "DIO1" in root sheet cannot be connected to non-existent parent sheet
    ; error
    @(180.34 mm, 35.56 mm): Hierarchical Label 'DIO1'
[pin_not_connected]: Hierarchical label "DIO2" in root sheet cannot be connected to non-existent parent sheet
    ; error
    @(180.34 mm, 38.10 mm): Hierarchical Label 'DIO2'
[pin_not_connected]: Hierarchical label "DIO3" in root sheet cannot be connected to non-existent parent sheet
    ; error
    @(180.34 mm, 40.64 mm): Hierarchical Label 'DIO3'
[pin_not_connected]: Hierarchical label "DIO4" in root sheet cannot be connected to non-existent parent sheet
    ; error
    @(180.34 mm, 43.18 mm): Hierarchical Label 'DIO4'
[pin_not_connected]: Hierarchical label "DIO5" in root sheet cannot be connected to non-existent parent sheet
    ; error
    @(180.34 mm, 45.72 mm): Hierarchical Label 'DIO5'
[pin_not_connected]: Hierarchical label "DIO6" in root sheet cannot be connected to non-existent parent sheet
    ; error
    @(180.34 mm, 48.26 mm): Hierarchical Label 'DIO6'
[pin_not_connected]: Hierarchical label "DIO7" in root sheet cannot be connected to non-existent parent sheet
    ; error
    @(180.34 mm, 50.80 mm): Hierarchical Label 'DIO7'
[pin_not_connected]: Hierarchical label "DIO8" in root sheet cannot be connected to non-existent parent sheet
    ; error
    @(180.34 mm, 53.34 mm): Hierarchical Label 'DIO8'
[pin_not_connected]: Pin not connected
    ; error
    @(180.34 mm, 55.88 mm): Symbol U1 Pin 25 [Pin_25, Passive, Line]
[pin_not_connected]: Pin not connected
    ; error
    @(180.34 mm, 58.42 mm): Symbol U1 Pin 27 [Pin_27, Passive, Line]
[pin_not_connected]: Pin not connected
    ; error
    @(180.34 mm, 60.96 mm): Symbol U1 Pin 29 [Pin_29, Passive, Line]
[pin_not_connected]: Pin not connected
    ; error
    @(180.34 mm, 63.50 mm): Symbol U1 Pin 31 [Pin_31, Passive, Line]
[pin_not_connected]: Pin not connected
    ; error
    @(180.34 mm, 66.04 mm): Symbol U1 Pin 33 [Pin_33, Passive, Line]
[pin_not_connected]: Pin not connected
    ; error
    @(180.34 mm, 68.58 mm): Symbol U1 Pin 35 [Pin_35, Passive, Line]
[pin_not_connected]: Pin not connected
    ; error
    @(193.04 mm, 30.48 mm): Symbol U1 Pin 6 [Pin_6, Passive, Line]
[pin_not_connected]: Pin not connected
    ; error
    @(193.04 mm, 33.02 mm): Symbol U1 Pin 8 [Pin_8, Passive, Line]
[pin_not_connected]: Pin not connected
    ; error
    @(193.04 mm, 35.56 mm): Symbol U1 Pin 10 [Pin_10, Passive, Line]
[pin_not_connected]: Pin not connected
    ; error
    @(193.04 mm, 38.10 mm): Symbol U1 Pin 12 [Pin_12, Passive, Line]
[pin_not_connected]: Pin not connected
    ; error
    @(193.04 mm, 40.64 mm): Symbol U1 Pin 14 [Pin_14, Passive, Line]
[pin_not_connected]: Pin not connected
    ; error
    @(193.04 mm, 43.18 mm): Symbol U1 Pin 16 [Pin_16, Passive, Line]
[pin_not_connected]: Pin not connected
    ; error
    @(193.04 mm, 45.72 mm): Symbol U1 Pin 18 [Pin_18, Passive, Line]
[pin_not_connected]: Pin not connected
    ; error
    @(193.04 mm, 48.26 mm): Symbol U1 Pin 20 [Pin_20, Passive, Line]
[pin_not_connected]: Pin not connected
    ; error
    @(193.04 mm, 50.80 mm): Symbol U1 Pin 22 [Pin_22, Passive, Line]
[pin_not_connected]: Hierarchical label "TE_DATA" in root sheet cannot be connected to non-existent parent sheet
    ; error
    @(193.04 mm, 53.34 mm): Hierarchical Label 'TE_DATA'
[pin_not_connected]: Hierarchical label "DAV" in root sheet cannot be connected to non-existent parent sheet
    ; error
    @(193.04 mm, 55.88 mm): Hierarchical Label 'DAV'
[pin_not_connected]: Hierarchical label "NRFD" in root sheet cannot be connected to non-existent parent sheet
    ; error
    @(193.04 mm, 58.42 mm): Hierarchical Label 'NRFD'
[pin_not_connected]: Hierarchical label "NDAC" in root sheet cannot be connected to non-existent parent sheet
    ; error
    @(193.04 mm, 60.96 mm): Hierarchical Label 'NDAC'
[pin_not_connected]: Hierarchical label "EOI" in root sheet cannot be connected to non-existent parent sheet
    ; error
    @(193.04 mm, 63.50 mm): Hierarchical Label 'EOI'
[pin_not_connected]: Hierarchical label "SCL" in root sheet cannot be connected to non-existent parent sheet
    ; error
    @(193.04 mm, 66.04 mm): Hierarchical Label 'SCL'
[pin_not_connected]: Hierarchical label "SDA" in root sheet cannot be connected to non-existent parent sheet
    ; error
    @(193.04 mm, 68.58 mm): Hierarchical Label 'SDA'
[pin_not_connected]: Hierarchical label "DIO1_B" in root sheet cannot be connected to non-existent parent sheet
    ; error
    @(215.90 mm, 25.40 mm): Hierarchical Label 'DIO1_B'
[pin_not_connected]: Hierarchical label "DIO2_B" in root sheet cannot be connected to non-existent parent sheet
    ; error
    @(215.90 mm, 27.94 mm): Hierarchical Label 'DIO2_B'
[pin_not_connected]: Hierarchical label "DIO3_B" in root sheet cannot be connected to non-existent parent sheet
    ; error
    @(215.90 mm, 30.48 mm): Hierarchical Label 'DIO3_B'
[pin_not_connected]: Hierarchical label "DIO4_B" in root sheet cannot be connected to non-existent parent sheet
    ; error
    @(215.90 mm, 33.02 mm): Hierarchical Label 'DIO4_B'
[pin_not_connected]: Hierarchical label "EOI_B" in root sheet cannot be connected to non-existent parent sheet
    ; error
    @(215.90 mm, 35.56 mm): Hierarchical Label 'EOI_B'
[pin_not_connected]: Hierarchical label "DAV_B" in root sheet cannot be connected to non-existent parent sheet
    ; error
    @(215.90 mm, 38.10 mm): Hierarchical Label 'DAV_B'
[pin_not_connected]: Hierarchical label "NRFD_B" in root sheet cannot be connected to non-existent parent sheet
    ; error
    @(215.90 mm, 40.64 mm): Hierarchical Label 'NRFD_B'
[pin_not_connected]: Hierarchical label "NDAC_B" in root sheet cannot be connected to non-existent parent sheet
    ; error
    @(215.90 mm, 43.18 mm): Hierarchical Label 'NDAC_B'
[pin_not_connected]: Hierarchical label "IFC_B" in root sheet cannot be connected to non-existent parent sheet
    ; error
    @(215.90 mm, 45.72 mm): Hierarchical Label 'IFC_B'
[pin_not_connected]: Hierarchical label "SRQ_B" in root sheet cannot be connected to non-existent parent sheet
    ; error
    @(215.90 mm, 48.26 mm): Hierarchical Label 'SRQ_B'
[pin_not_connected]: Hierarchical label "ATN_B" in root sheet cannot be connected to non-existent parent sheet
    ; error
    @(215.90 mm, 50.80 mm): Hierarchical Label 'ATN_B'
[power_pin_not_driven]: Input Power pin not driven by any Output Power pins
    ; error
    @(215.90 mm, 53.34 mm): Symbol #PWR001 Pin 1 [Power input, Line]
[pin_not_connected]: Hierarchical label "DIO5_B" in root sheet cannot be connected to non-existent parent sheet
    ; error
    @(228.60 mm, 25.40 mm): Hierarchical Label 'DIO5_B'
[pin_not_connected]: Hierarchical label "DIO6_B" in root sheet cannot be connected to non-existent parent sheet
    ; error
    @(228.60 mm, 27.94 mm): Hierarchical Label 'DIO6_B'
[pin_not_connected]: Hierarchical label "DIO7_B" in root sheet cannot be connected to non-existent parent sheet
    ; error
    @(228.60 mm, 30.48 mm): Hierarchical Label 'DIO7_B'
[pin_not_connected]: Hierarchical label "DIO8_B" in root sheet cannot be connected to non-existent parent sheet
    ; error
    @(228.60 mm, 33.02 mm): Hierarchical Label 'DIO8_B'
[pin_not_connected]: Hierarchical label "REN_B" in root sheet cannot be connected to non-existent parent sheet
    ; error
    @(228.60 mm, 35.56 mm): Hierarchical Label 'REN_B'
[pin_not_connected]: Hierarchical label "LDO_IN" in root sheet cannot be connected to non-existent parent sheet
    ; error
    @(251.46 mm, 30.48 mm): Hierarchical Label 'LDO_IN'
[power_pin_not_driven]: Input Power pin not driven by any Output Power pins
    ; error
    @(251.46 mm, 30.48 mm): Symbol U5 Pin 3 [VI, Power input, Line]
[lib_symbol_mismatch]: Symbol 'MCP23017_SO' doesn't match copy in library 'Interface_Expansion'
    ; warning
    @(45.72 mm, 55.88 mm): Symbol U4 [MCP23017_SO]
[lib_symbol_issues]: The current configuration does not include the symbol library 'AR488_custom'
    ; warning
    @(99.06 mm, 53.34 mm): Symbol U3 [SN75161BN]
[lib_symbol_issues]: The current configuration does not include the symbol library 'AR488_custom'
    ; warning
    @(33.02 mm, 139.70 mm): Symbol Q1 [AO4407A]
[footprint_link_issues]: The current configuration does not include the footprint library 'AR488_custom'.
    ; warning
    @(185.42 mm, 45.72 mm): Symbol U1 [Conn_02x18_Odd_Even]
[footprint_link_issues]: The current configuration does not include the footprint library 'AR488_custom'.
    ; warning
    @(220.98 mm, 38.10 mm): Symbol J1 [Conn_02x12_Odd_Even]

 ** ERC messages: 131  Errors 126  Warnings 5

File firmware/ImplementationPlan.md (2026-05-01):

This plan focuses on building a **Dual-Core "Gateway"** firmware. It treats the GPIB bus as a protected resource, allowing you to run a high-performance JSON/MCP interface today while leaving a "slot" open for a Legacy Prologix-style task later.

### `Implementation\\\_Plan.md`

# Project: Modern AI-GPIB Gateway (ESP32 to Tektronix 784)

## Overview

A streamlined ESP32 firmware designed for AI-driven laboratory automation. It utilizes a non-blocking WebSocket/JSON interface for modern agents (via MCP) and provides a thread-safe path for legacy IEEE-488.2 compatibility.

Hardware is the Heltec ESP32 Wifi Kit V1 with OLED

## Phase 1: The Hardware Abstraction Layer (HAL)

**Goal:** Create a thread-safe C++ Class using direct register access.

### 1.1 `GpibBus` Class Definition

- **Encapsulation:** Protect GPIB pins using a FreeRTOS Mutex (`SemaphoreHandle\\\_t`).

- **Register Mapping:** Define macros for GPIO Port A/B writes for the 8-bit data bus.

- **Handshake Logic:** Implement `write\\\_byte` and `read\\\_byte` using the 3-wire handshake (DAV, NRFD, NDAC).

### 1.2 Validation (Test 1)

- **Flash firmware.**

- **Detect GPIB connection and indicate detection on the OLED**

- **Test:** send `\\\*IDN?` query to the Tek 784.

- **Success Criteria:** The scope returns `"TEKTRONIX,784..."` without timing out.

- Display return value on the OLED

## Phase 2: The Modern Communication Core

**Goal:** Establish a JSON-over-WebSocket transport on Core 0.

implementation note: use the file network\_creds.h to connect to local Wifi AP

### 2.1 Async WebSocket Server

- Use `ESPAsyncWebServer` to handle incoming JSON frames.

- **Protocol:**

- JSON

`\\\{`

- `  "request\\\_id": "123",`

- ` "action": "query",`

- `  "command": "CH1:SCALE?"`

- `\\\}`

```
  
\#\#\# 2.2 Command Dispatcher  
  
- Parse JSON using \`ArduinoJson\`.  
  
- Acquire the \`GpibBus\` mutex.  
  
- Execute the command on the bus and capture the response.  
  
- Return a JSON response frame.  
  
\#\#\# 2.3 Validation (Test 2)  
  
- \*\*Flash firmware.\*\*  
  
- \*\*Report IP address on OLED\*\*  
  
- \*\*Test:\*\*  Make a Python script to send a WebSocket JSON request for the scope's horizontal scale.  
  
- \*\*Do some communication traces on the OLED\*\*  
  
- \*\*Success Criteria:\*\* Valid JSON received containing the numeric scale value.  

\#\# Phase 3: High-Bandwidth Data Handling  
  
\*\*Goal:\*\* Efficiently handle large waveform captures (CURVe? data).  
  
\#\#\# 3.1 Binary Pass-through  
  
- Detect when a command expects a large binary payload (e.g., \`CURV?\`).  
  
- Implement a "Raw Mode" where the HAL streams bytes directly from the bus to the WebSocket buffer to avoid memory fragmentation on the ESP32.  
  
\#\#\# 3.2 Validation (Test 3)  
  
- \*\*Test:\*\* Request a 5,000-point waveform capture.  
  
- \*\*Success Criteria:\*\* Data is received in under 500ms and matches the visual representation on the scope.  

\#\# Phase 4: MCP Integration (Local Machine)  
  
\*\*Goal:\*\* Bridge the AI to the ESP32.  
  
\#\#\# 4.1 Python MCP Server  
  
- Implement an MCP server using the Python SDK.  
  
- Define Tools: \`get\\\_waveform\`, \`set\\\_vertical\\\_scale\`, \`auto\\\_setup\`.  
  
- The server maintains a persistent WebSocket connection to the ESP32.  
  
\#\#\# 4.2 Validation (Test 4)  
  
- \*\*Test:\*\* Prompt the AI: \*"Analyze the signal on Channel 1 and tell me if the rise time is within TTL specs."\*  
  
- \*\*Success Criteria:\*\* AI triggers the tools, receives the data, and provides a correct engineering analysis.  

\#\# Phase 5: Legacy Compatibility Layer (Future Slot)  
  
\*\*Goal:\*\* Open a Telnet port for legacy software.  
  
\#\#\# 5.1 The "Prologix" Task  
  
- Initialize a second listening port (Telnet 1234).  
  
- Create a "Legacy Parser" that translates \`++addr\` and \`++read\` into \`GpibBus\` class calls.  
  
- \*\*Constraint:\*\* Ensure this task requests the same \`GpibBus\` mutex used by the WebSocket task.  

\#\# Development Milestones & Checklist  
  
- \\\[ \\\] \*\*Milestone 1:\*\* Basic register-based handshake working (verified by Logic Analyzer or Scope ID).  
  
- \\\[ \\\] \*\*Milestone 2:\*\* Mutex-protected bus access (prevents crashes during simultaneous requests).  
  
- \\\[ \\\] \*\*Milestone 3:\*\* WebSocket server reliably delivering SCPI responses.  
  
- \\\[ \\\] \*\*Milestone 4:\*\* MCP Server operational and "Tools" recognized by the AI Agent.  

\#\#\# Key Technical Notes for the Agent  

- \*\*Timeouts:\*\* Implement a hard 2-second watchdog on the \`NDAC\` line to prevent the ESP32 from hanging if the scope is disconnected.  
  
- \*\*Core Affinity:\*\* Force the WiFi/WebSocket task to \`Core 0\` and the GPIB HAL to \`Core 1\` for maximum timing stability.
```

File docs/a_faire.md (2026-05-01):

## 1.0 general design
Using kicad, design a circuit similar to the https://oshpark.com/profiles/artag ar488promicro
A sibling work is in https://github.com/artgodwin/AR488-32u4-PCB, these 2 examples should be use only to have a layout example as all the details are wrong.
The main idea is to have the PCB parallel to the back of the plug. Keep the 2 holes spaced 46.3 mm on each side of the length of the connector. The PCB length in the direction of the connector is 11cm maximum with the connector at the center. The PCB width can extend 1.5cm from the connector center on the side of pins 1 to 12, the PCB width can extend 4.5 cm on the side of pins 13-24.

### 1.0.1 Architecture decisions

**Target instrument:** Tektronix TDS784A (fast GPIB instrument, 200-500 KB/s).

**GPIO hybrid architecture:** The Heltec WiFi Kit 32 V2 has only 16 bidirectional GPIOs available (OLED uses GPIO4/15/16). GPIB needs 18+ signals. Solution: use an MCP23017 I2C GPIO expander (SOIC-28) for slow management signals, keeping data and handshake lines on direct GPIOs for zero-latency data transfer.

**Signal split:**
- **Direct ESP32 GPIOs (fast path):** DIO1-DIO8 (8 data), DAV, NRFD, NDAC (3 handshake), EOI (1 end-of-message), TE_data (1 SN75160B talk enable), I2C SDA/SCL (2) = 15 GPIOs
- **MCP23017 (slow path, accessed only on mode changes):** ATN, IFC, SRQ, REN, TE_ctrl (SN75161B talk enable), DC (SN75161B direction control) = 6 signals

**TE lines:** Separate — TE_data on direct GPIO for SN75160B, TE_ctrl on MCP23017 for SN75161B.

**Level shifting:** Direct 3.3V to 5V TTL connection (no level shifters). ESP32 3.3V outputs exceed SN7516x D-side TTL HIGH threshold (~1.5V).

**GPIO assignments:**

| Signal | ESP32 GPIO | Destination |
|---|---|---|
| DIO1 | GPIO13 | SN75160B D1 (pin 19) |
| DIO2 | GPIO12 | SN75160B D2 (pin 18) |
| DIO3 | GPIO14 | SN75160B D3 (pin 17) |
| DIO4 | GPIO27 | SN75160B D4 (pin 16) |
| DIO5 | GPIO26 | SN75160B D5 (pin 15) |
| DIO6 | GPIO25 | SN75160B D6 (pin 14) |
| DIO7 | GPIO33 | SN75160B D7 (pin 13) |
| DIO8 | GPIO32 | SN75160B D8 (pin 12) |
| TE_data | GPIO17 | SN75160B TE (pin 1) |
| DAV | GPIO5 | SN75161B DAV term (pin 15) |
| NRFD | GPIO18 | SN75161B NRFD term (pin 16) |
| NDAC | GPIO23 | SN75161B NDAC term (pin 17) |
| EOI | GPIO19 | SN75161B EOI term (pin 14) |
| I2C SDA | GPIO21 | MCP23017 SDA |
| I2C SCL | GPIO22 | MCP23017 SCL |

| Signal | MCP23017 Pin | Destination |
|---|---|---|
| ATN | GPA0 | SN75161B ATN term (pin 13) |
| IFC | GPA1 | SN75161B IFC term (pin 18) |
| SRQ | GPA2 | SN75161B SRQ term (pin 12) |
| REN | GPA3 | SN75161B REN term (pin 19) |
| TE_ctrl | GPA4 | SN75161B TE (pin 1) |
| DC | GPA5 | SN75161B DC (pin 11) |

### 1.1 specific component footprints
#### 1.1.1 Centronics 24 pin plug
The centronics 24 plug is a solder type with 2 raws of 12 pins, each pin is 1.45 mm in diameter, this leads to a pcb hole diameter of 1.5mm, the spacing between each of the 12 pins in a row is 2.159mm center to center, the spacing center to center between the 2 rows is 4.45mm.
#### 1.1.2 Microprocessor module
The microprocessor module is an ESP32 Wifi Kit 32 V2 from Heltec, based on ESP32 with built-in OLED display. The mechanical interface is 2 rows of 18 pin headers spaced 22.86mm, 2.54mm pitch. The module has a 5V pin (from USB) on the right header, position 2.
#### 1.1.3 interface ICs
Due to voltage requirements of the bus, there need to be
- SN75160B — Data Bus (8 lines)
This IC is available in smd, reference SN75160BDWR (SOIC-20W)
KiCad symbol: `Interface:SN75160BDW`
Handling DIO1–DIO8 Bidirectional. ~PE pin tied to VCC (3-state mode).

Direction pin (TE) selects talk/listen mode.
- SN75161B — Control Bus
This IC is only available in DIP20 reference SN75161BN
KiCad symbol: custom (not in standard library)
Handling the management lines:

  - ATN
  - DAV
  - NRFD
  - NDAC
  - IFC
  - SRQ
  - REN
  - EOI

Direction controlled by TE (handshake lines) and DC (management lines).

#### 1.1.4 I2C GPIO expander
MCP23017 in SOIC-28 package. KiCad symbol: `Interface_Expansion:MCP23017_SO`.
I2C address 0x20 (A0=A1=A2=GND). RESET pin tied to VCC via 10kΩ pullup.
Handles slow management signals (ATN, IFC, SRQ, REN, TE_ctrl, DC) — accessed only during bus mode changes, not during data transfer.

#### 1.1.5 Power supply
5V power is either supplied to the microprocessor module through USB, or through a 5.5mm barrel jack (7-12V DC input).

**Reverse polarity protection:** AO4407A P-channel MOSFET (SOIC-8). Source to jack V+, drain to LDO input, gate to GND via 100kΩ resistor. Near-zero voltage drop (~2.4mV at 200mA) vs ~300mV for a Schottky diode.

**Voltage regulation:** AMS1117-5.0 LDO in SOT-223 package. Input capacitor: 10µF ceramic 0805. Output capacitor: 10µF ceramic 0603.

**Decoupling capacitors:**
- SN75160B: 100nF 0603 + 22µF 0603
- SN75161B: 100nF 0603 + 22µF 0603
- MCP23017: 100nF 0603

## for V2

# Hardware Improvements & Known Issues (TODO)

This document tracks identified hardware risks and recommended revisions for the **AR-488-ESP32** project to ensure reliable operation with high-performance laboratory equipment like the **Tektronix TDS 784**.

## 1. Logic Level Protection (Current Limiting)
* **Issue:** The SN7516x transceivers are 5V TTL devices. Their logic "High" output ($V_{OH}$) can exceed 3.6V, which is the absolute maximum rating for the ESP32 GPIOs.
* **Action:** Add **330Ω series resistors** between every ESP32 GPIO and its corresponding SN7516x pin. This protects the ESP32 from overvoltage and limits current through internal ESD protection diodes.

## 2. Boot Strapping Pin Conflicts (Critical)
The ESP32 samples specific pins at power-up to determine its boot mode. If the GPIB bus is active, it can "back-drive" these pins and prevent the ESP32 from starting.
* **GPIO 12 (MTDI):** Must be **LOW** at boot for 3.3V Flash voltage. If High, the ESP32 will boot-loop.
* **GPIO 2:** Must be **LOW** or floating at boot.
* **GPIO 0:** Must be **HIGH** for normal execution (currently safe via pull-up/button).
* **Fix:** Ensure the SN7516x **Enable (EN)** or **Direction (TE/DC)** pins are pulled to a state that keeps the transceiver in **High-Impedance (High-Z)** mode during power-on.

## 3. JTAG / ESP-PROG Compatibility
* **Issue:** The project currently utilizes **GPIO 12, 13, 14, and 15**. These are reserved for the JTAG interface used by the ESP-PROG debugger.
* **Impact:** Real-time hardware debugging is currently impossible while the GPIB interface is connected.
* **Action:** Consider remapping GPIB signals to non-JTAG pins (e.g., GPIOs 16, 17, 18, 19, 21, 22, 23, 25, 26, 27) to allow for simultaneous debugging.
* **Action** implement a convenient JTAG connector

## 4. Power & Decoupling
* **Action:** Tie the **GPIB Shield (Pin 12)** to the PCB digital ground to improve signal integrity during high-speed waveform transfers from the TDS 784.

## 5. Software-Side Initialization
* **Action:** The firmware `setup()` function must immediately set the Transceiver Control pins (TE/DC) to a "Listen" or "High-Z" state to release the strapping pins as quickly as possible after power-up.

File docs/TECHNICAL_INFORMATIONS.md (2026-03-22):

# Technical Information — AR-488-ESP32 GPIB Interface

## Heltec WiFi Kit 32 V2 (ESP32) — Complete Pinout

Board orientation: USB connector at bottom, OLED at top. 2x18 pin headers, 22.86mm row spacing.

### Left Row (top to bottom)

| Pos | Label | GPIO | Notes |
|-----|---|---|---|
| 1 | GND | -- | Power |
| 2 | 3V3 | -- | 3.3V output |
| 3 | Vext | -- | Switchable 3.3V (controlled by GPIO21) |
| 4 | RST | -- | Reset |
| 5 | 13 | GPIO13 | ADC2_4, Touch4 |
| 6 | 12 | GPIO12 | ADC2_5, Touch5 — strapping pin (LOW at boot) |
| 7 | 14 | GPIO14 | ADC2_6, Touch6 |
| 8 | 27 | GPIO27 | ADC2_7, Touch7 |
| 9 | 26 | GPIO26 | DAC2, ADC2_9 |
| 10 | 25 | GPIO25 | DAC1, ADC2_8 — on-board LED |
| 11 | 33 | GPIO33 | ADC1_5, Touch8 |
| 12 | 32 | GPIO32 | ADC1_4, Touch9 |
| 13 | 35 | GPIO35 | ADC1_7 — **input only** |
| 14 | 34 | GPIO34 | ADC1_6 — **input only** |
| 15 | 39 | GPIO39 | ADC1_3 — **input only** |
| 16 | 38 | GPIO38 | ADC1_2 — **input only** |
| 17 | 37 | GPIO37 | ADC1_1 — **input only** |
| 18 | 36 | GPIO36 | ADC1_0 — **input only** |

### Right Row (top to bottom)

| Pos | Label | GPIO | Notes |
|-----|---|---|---|
| 1 | GND | -- | Power |
| 2 | 5V | -- | **5V output from USB** |
| 3 | 3V3 | -- | 3.3V output |
| 4 | Vext | -- | Switchable 3.3V |
| 5 | TX | GPIO1 | U0_TXD — serial programming |
| 6 | RX | GPIO3 | U0_RXD — serial programming |
| 7 | 15 | GPIO15 | **OLED_SCL (reserved)** |
| 8 | 2 | GPIO2 | Strapping pin |
| 9 | 0 | GPIO0 | **PROG button**, strapping |
| 10 | 4 | GPIO4 | **OLED_SDA (reserved)** |
| 11 | 16 | GPIO16 | **OLED_RST (reserved)** |
| 12 | 17 | GPIO17 | U2_TXD |
| 13 | 5 | GPIO5 | V_SPI_CS0 — strapping pin |
| 14 | 18 | GPIO18 | V_SPI_CLK |
| 15 | 23 | GPIO23 | V_SPI_MOSI |
| 16 | 19 | GPIO19 | V_SPI_MISO |
| 17 | 22 | GPIO22 | I2C SCL |
| 18 | 21 | GPIO21 | I2C SDA — also Vext control |

### GPIO Classification

**OLED reserved (3):** GPIO4 (SDA), GPIO15 (SCL), GPIO16 (RST)

**Input-only (6):** GPIO34, GPIO35, GPIO36, GPIO37, GPIO38, GPIO39

**Bidirectional, free for use (16):**
GPIO2, GPIO5, GPIO12, GPIO13, GPIO14, GPIO17, GPIO18, GPIO19, GPIO21, GPIO22, GPIO23, GPIO25, GPIO26, GPIO27, GPIO32, GPIO33

**Avoid:** GPIO0 (boot button), GPIO1 (TX), GPIO3 (RX), GPIO6-11 (internal flash)

### Sources
- Official pinout diagram: https://resource.heltec.cn/download/WiFi_Kit_32/WIFI_Kit_32_pinoutDiagram_V2.pdf
- Heltec documentation: https://docs.heltec.org/en/node/esp32/wifi_kit_32/index.html
- ESP32 GPIO reference: https://randomnerdtutorials.com/esp32-pinout-reference-gpios/

---

## SN75160BDW — GPIB Data Bus Transceiver (SOIC-20)

KiCad symbol: `Interface:SN75160BDW`
KiCad footprint: `Package_SO:SOIC-20W_7.5x12.8mm_P1.27mm`

### Pinout

| Pin | Name | Function |
|-----|---|---|
| 1 | TE | Talk Enable (input) — HIGH=transmit, LOW=receive |
| 2 | B1 | GPIB bus DIO1 |
| 3 | B2 | GPIB bus DIO2 |
| 4 | B3 | GPIB bus DIO3 |
| 5 | B4 | GPIB bus DIO4 |
| 6 | B5 | GPIB bus DIO5 |
| 7 | B6 | GPIB bus DIO6 |
| 8 | B7 | GPIB bus DIO7 |
| 9 | B8 | GPIB bus DIO8 |
| 10 | GND | Ground |
| 11 | ~{PE} | Pull-up Enable (input) — active LOW. Tie to VCC for 3-state mode |
| 12 | D8 | Terminal DIO8 (MCU side) |
| 13 | D7 | Terminal DIO7 |
| 14 | D6 | Terminal DIO6 |
| 15 | D5 | Terminal DIO5 |
| 16 | D4 | Terminal DIO4 |
| 17 | D3 | Terminal DIO3 |
| 18 | D2 | Terminal DIO2 |
| 19 | D1 | Terminal DIO1 |
| 20 | VCC | +5V supply (4.75-5.25V) |

**Notes:** D-side pins are in reverse order (D8=pin12, D1=pin19). B-side (bus) is B1=pin2 to B8=pin9.

### Source
- TI Datasheet: https://www.ti.com/lit/ds/symlink/sn75160b.pdf

---

## SN75161BN — GPIB Control Bus Transceiver (DIP-20)

**Not in KiCad 9.0 standard library — custom symbol required.**

### Pinout

| Pin | Name | Function |
|-----|---|---|
| 1 | TE | Talk Enable (input) — controls DAV, NRFD, NDAC direction |
| 2 | REN (bus) | Remote Enable — GPIB bus side |
| 3 | IFC (bus) | Interface Clear — GPIB bus side |
| 4 | NDAC (bus) | Not Data Accepted — GPIB bus side |
| 5 | NRFD (bus) | Not Ready For Data — GPIB bus side |
| 6 | DAV (bus) | Data Valid — GPIB bus side |
| 7 | EOI (bus) | End Or Identify — GPIB bus side |
| 8 | ATN (bus) | Attention — GPIB bus side |
| 9 | SRQ (bus) | Service Request — GPIB bus side |
| 10 | GND | Ground |
| 11 | DC | Direction Control (input) — controls ATN, SRQ, REN, IFC direction |
| 12 | SRQ (term) | Service Request — terminal/MCU side |
| 13 | ATN (term) | Attention — terminal side |
| 14 | EOI (term) | End Or Identify — terminal side |
| 15 | DAV (term) | Data Valid — terminal side |
| 16 | NRFD (term) | Not Ready For Data — terminal side |
| 17 | NDAC (term) | Not Data Accepted — terminal side |
| 18 | IFC (term) | Interface Clear — terminal side |
| 19 | REN (term) | Remote Enable — terminal side |
| 20 | VCC | +5V supply (4.75-5.25V) |

**Direction control:**
- TE controls direction of DAV, NRFD, NDAC
- DC controls direction of ATN, SRQ, REN, IFC
- EOI direction controlled by TE AND DC jointly

### Source
- TI Datasheet: https://www.ti.com/lit/ds/symlink/sn75161b.pdf

---

## GPIB IEEE-488 Centronics 24-Pin Connector Pinout

| Pin | Signal | Type | Pin | Signal | Type |
|-----|---|---|-----|---|---|
| 1 | DIO1 | Data | 13 | DIO5 | Data |
| 2 | DIO2 | Data | 14 | DIO6 | Data |
| 3 | DIO3 | Data | 15 | DIO7 | Data |
| 4 | DIO4 | Data | 16 | DIO8 | Data |
| 5 | EOI | Management | 17 | REN | Management |
| 6 | DAV | Handshake | 18 | GND (DAV ret) | Ground |
| 7 | NRFD | Handshake | 19 | GND (NRFD ret) | Ground |
| 8 | NDAC | Handshake | 20 | GND (NDAC ret) | Ground |
| 9 | IFC | Management | 21 | GND (IFC ret) | Ground |
| 10 | SRQ | Management | 22 | GND (SRQ ret) | Ground |
| 11 | ATN | Management | 23 | GND (ATN ret) | Ground |
| 12 | SHIELD | Ground | 24 | GND (Logic) | Ground |

**Ground pins:** 12, 18, 19, 20, 21, 22, 23, 24

### Source
- IEEE 488.1 standard
- NI GPIB concepts: https://www.ni.com/docs/en-US/bundle/gpib-help/page/gpib-concepts/gpib_concepts.html

---

## MCP23017 — I2C 16-bit GPIO Expander

KiCad symbol: `Interface_Expansion:MCP23017_SO` (SOIC-28)
KiCad footprint: `Package_SO:SOIC-28W_7.5x17.9mm_P1.27mm`

- **I2C speed:** up to 1.7 MHz
- **VCC range:** 1.8V–5.5V (works at 3.3V)
- **Outputs:** 25mA push-pull per pin
- **Interrupt:** per-pin configurable, active-low/high or open-drain
- **Address pins:** A0, A1, A2 — up to 8 devices on one bus (base address 0x20)
- **Latency:** ~20µs per byte at 1 MHz I2C

### Source
- Microchip datasheet: https://ww1.microchip.com/downloads/en/DeviceDoc/20001952C.pdf

---

## Tektronix TDS784A — GPIB Performance

- **GPIB standard:** IEEE-488.2, supports HS488
- **Transfer rate:** 200–500 KB/s sustained (standard mode), up to 1.2 MB/s with HS488
- **Handshake cycle:** 2–5 µs (standard), 1–2 µs (HS488)
- **Classification:** Fast GPIB instrument (NOT slow despite some claims)
- **HS488 T1:** 350 ns minimum

### Source
- Tek programmer manual: https://www.tek.com/en/manual/tds784a-tds784c-tds784d-programmer-manual
- NI HS488: https://www.ni.com/docs/en-US/bundle/gpib-help/page/gpib-concepts/hs488-protocol.html

---

## Architecture Decision: Hybrid GPIO + MCP23017

### Signal Split

**Direct ESP32 GPIOs (fast path — 15 signals):**
- DIO1–DIO8 (8 data lines) — change every byte
- DAV, NRFD, NDAC (3 handshake lines) — change every byte
- EOI (1 line) — end-of-message detection
- TE_data (1 line) — SN75160B talk enable
- I2C SDA, SCL (2 lines) — for MCP23017

**MCP23017 (slow path — 5 signals, accessed only on mode changes):**
- ATN — once per command sequence
- IFC — once per session (bus reset)
- SRQ — occasional polling
- REN — once per session
- TE_ctrl (SN75161B talk enable)
- DC (SN75161B direction control)

**Total ESP32 GPIOs used: 15** (13 signals + 2 I2C). Available: 16. **1 spare.**

**Result:** Zero I2C overhead during data transfer. Full TDS784A speed preserved.

---

## Reverse Polarity Protection — P-FET (AO3401A)

Instead of a Schottky diode (~300mV drop), use a P-channel MOSFET for near-zero dropout protection.

**Selected part: AO4407A** (SOIC-8)
- Vds: -30V (plenty of margin for 12V input)
- Rds(on): 12mΩ typ @ Vgs=-4.5V
- Vgs(th): -1V to -3V
- Vgs max: ±20V (no Zener clamp needed at 7-12V input)
- Id: -12A continuous
- Voltage drop @ 200mA: **~2.4mV** (vs ~300mV for Schottky)
- Package: SOIC-8 (pins 1-3 = Source, pin 4 = Gate, pins 5-8 = Drain)
- KiCad symbol: **custom required** (not in KiCad 9.0 standard library)
- Datasheet: https://www.aosmd.com/res/datasheets/AO4407A.pdf

**Circuit:**
- Source → barrel jack V+ (7-12V)
- Drain → AMS1117-5.0 VIN
- Gate → GND via 100kΩ pull-down resistor (R_gate)

**How it works:** Normal polarity: Vgs is large negative → FET fully on, millivolt drop. Reverse polarity: Vgs ≥ 0 → FET off, body diode reverse-biased, no current flows.

### Sources
- AO3401A datasheet: https://www.aosmd.com/sites/default/files/res/datasheets/AO3401A.pdf
- Design guide: https://components101.com/articles/design-guide-pmos-mosfet-for-reverse-voltage-polarity-protection

---

## KiCad Component Summary

| Component | KiCad Symbol | KiCad Footprint | In Std Library? |
|---|---|---|---|
| SN75160BDW | `Interface:SN75160BDW` | `Package_SO:SOIC-20W_7.5x12.8mm_P1.27mm` | Yes |
| SN75161BN | **Custom required** | `Package_DIP:DIP-20_W7.62mm` | No |
| AMS1117-5.0 | `Regulator_Linear:AMS1117-5.0` | `Package_TO_SOT_SMD:SOT-223-3_TabPin2` | Yes |
| MCP23017 (SOIC) | `Interface_Expansion:MCP23017_SO` | `Package_SO:SOIC-28W_7.5x17.9mm_P1.27mm` | Yes |
| Barrel Jack | `Connector:Barrel_Jack` | `Connector_BarrelJack:BarrelJack_Horizontal` | Yes |
| 2x18 pin header | `Connector_Generic:Conn_02x18_Odd_Even` | custom (22.86mm spacing) | Symbol yes |
| 2x12 connector | `Connector_Generic:Conn_02x12_Odd_Even` | custom (Centronics 24) | Symbol yes |
| AO4407A (P-FET) | **Custom required** | `Package_SO:SOIC-8_3.9x4.9mm_P1.27mm` | No |
| Cap 0805 | `Device:C` | `Capacitor_SMD:C_0805_2012Metric` | Yes |
| Cap 0603 | `Device:C` | `Capacitor_SMD:C_0603_1608Metric` | Yes |
| Resistor 0603 | `Device:R` | `Resistor_SMD:R_0603_1608Metric` | Yes |

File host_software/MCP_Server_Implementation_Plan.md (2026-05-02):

# MCP Server Implementation Plan — TDS784A

Companion to `MCP_Tools_for_TDS784A_measurements_revised.md`. The proposal
defines *what*; this file defines *how*.

## File layout

```
host_software/
├── request_gpib.py              ← existing CLI; library symbols annotated
├── mcp_server/
│   ├── __init__.py
│   ├── __main__.py              ← `python -m mcp_server` entry
│   ├── server.py                ← FastMCP app, tools, scope ops, error drain
│   └── client.py                ← persistent WS wrapper
├── pyproject.toml               ← add `mcp[cli]`; keep `pillow`, `websockets`
├── ../.claude/skills/scope.md   ← /scope skill
└── ../.mcp.json                 ← add `tek-tds784a` server entry
```

Two new modules, not five. `errors.py` and `scope.py` collapse into
`server.py` — the helpers are short and only the server uses them.

## Order of work

### 1. Annotate `request_gpib.py` for reuse
Add a `# MCP-LIBRARY:` comment to each symbol the MCP imports. No code
edits. The CLI surface (`parse_args`, `run_*`, `main`) is free to evolve;
the annotated functions are not.

Symbols to annotate: `iso_stamp`, `parse_ieee_block`, `parse_wfmpre`,
`_FLOAT_RE`, `one_shot`, `query_value`, `query_preamble`, `decode_samples`,
`_setup_channel`, `_set_window`, `capture_channel`, `collect_metadata`,
`pcx_bytes_to_png`, `_HARDCOPY_*`, `make_request`, `_GLOBAL_META_QUERIES`,
`_PER_CHANNEL_META_QUERIES`.

### 2. `mcp_server/client.py` — connection wrapper
- One persistent `websockets.connect`, lifetime = MCP server lifetime.
- One `asyncio.Lock` around send/recv (Claude can issue concurrent calls).
- `request(action, command, expect_binary)` reusing `make_request` and
  `one_shot` from `request_gpib.py`.
- Env: `AR488_HOST`, `AR488_ADDR`, `AR488_TIMEOUT_MS`.
- No reconnect logic, no caching. If the WS dies, restart the server.

### 3. `mcp_server/server.py` — tools + helpers
Includes a small `drain_errors(client)` (runs `*ESR?` and `ALLEv?`) and
the composite ops (`arm_single_and_wait`, `atomic_capture`, `polled_stats`,
`acq_stats`). Tools register in this order so each layer is testable
before the next is built on top:

1. **Plumbing**: `raw_scpi`, `verify_instrument_identity`, `get_errors`,
   `wait_operation_complete`.
2. **Setup state**: `get_setup_state`, `set_setup_state(confirm)`,
   `save_internal`, `recall_internal`, `factory_reset(confirm)`.
3. **Acquisition**: `autoset`, `set_acquisition_mode`, `set_average_count`,
   `set_acquisition_state`, `arm_single_and_wait`.
4. **Vertical / horizontal / trigger**: `set_vertical`, `set_horizontal`,
   `set_trigger_edge`, `get_acquisition_setup`.
5. **Measurements**: `measure`, `measure_snapshot`,
   `set_measurement_ref_levels`, `measure_with_acq_stats`,
   `measure_with_polled_stats`.
6. **Waveform**: `get_waveform` (atomic multi-channel).
7. **Screen**: `get_screen` returns
   `ImageContent(type="image", data=b64, mimeType="image/png")` plus
   metadata.

### 4. Hardware-in-the-loop smoke test
Walk through each tool once against the live scope. No mocks, no automated
test harness — single user, single instrument.

### 5. Skill `~/.claude/skills/scope.md`
Short frontmatter triggers on "TDS784" / "oscilloscope". Body lists the
v1 tools, the AVERAGE-vs-polled stats trade-off, the confirm-required
tools, and points at `raw_scpi` for anything missing.

### 6. `.mcp.json` entry
Add `tek-tds784a` invoked as `uv run python -m mcp_server` with
`AR488_HOST` from env. KiCad entry untouched.

## Open items (resolve while implementing)

- **SET? size and timing** on this firmware — set the per-call timeout.
- **`MEASUREMENT:TYPE` enum values** — query the scope; the manual lists
  25 but exact mnemonics matter for the schema.
- **Trigger holdoff range** — verify on the live unit.

## Time estimate

~2 days: half a day for steps 1–2, one day for step 3, half a day for
4–6. Gated on live-scope access.

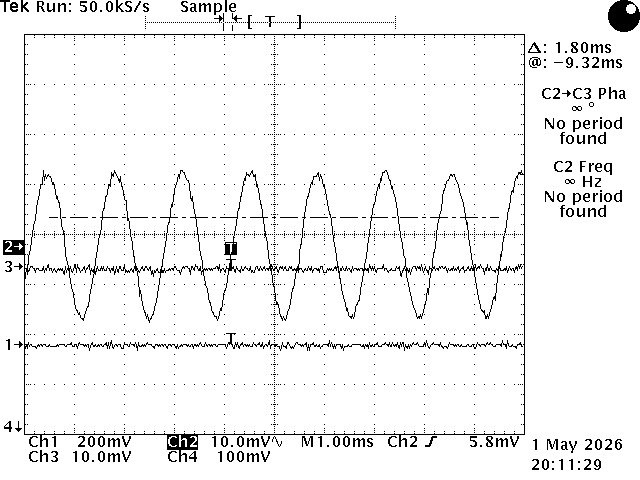
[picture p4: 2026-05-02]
docs/gpib_screen_bw.png

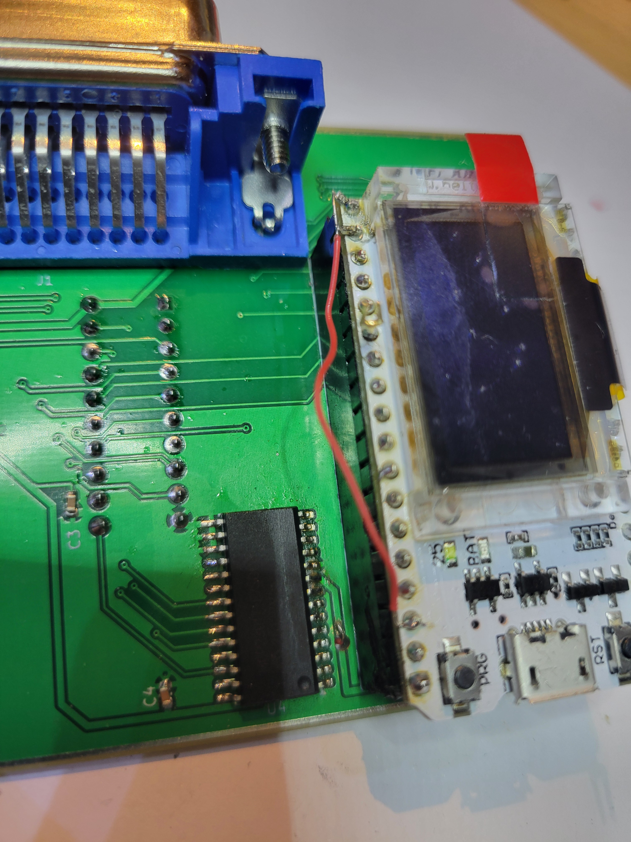
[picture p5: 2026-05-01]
docs/PCB_patched_area_front.jpg

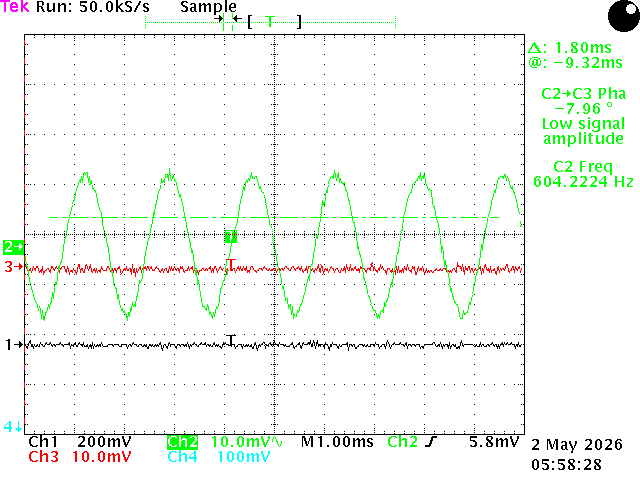
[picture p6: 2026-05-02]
docs/gpib_screen_colored.png

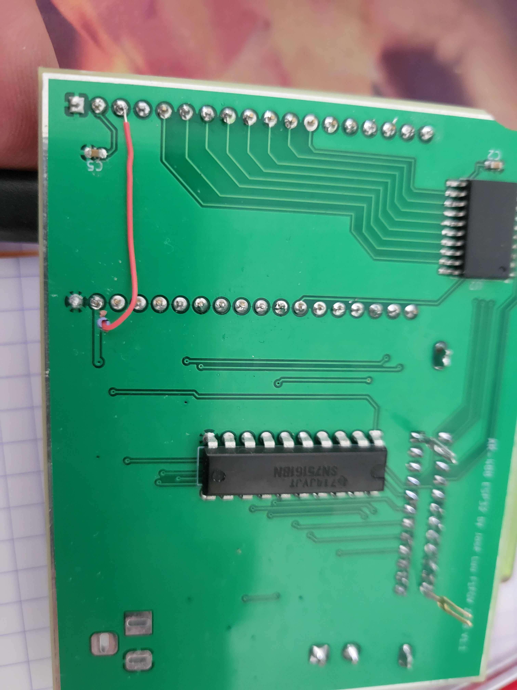
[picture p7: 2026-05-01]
docs/Patched_PCB_back.jpg

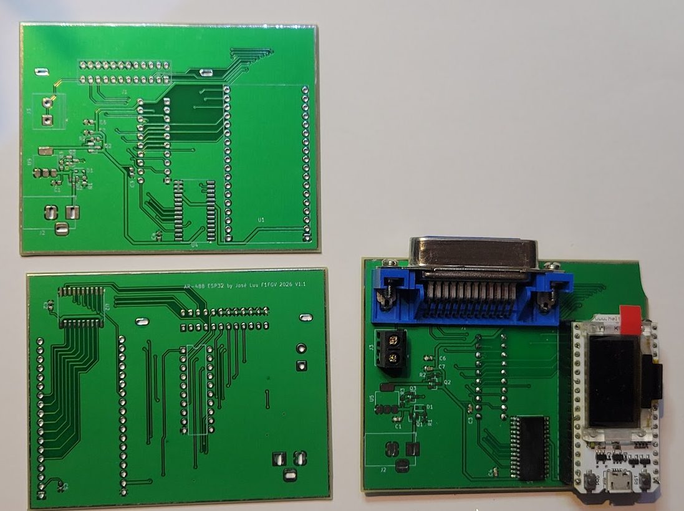
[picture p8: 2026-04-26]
docs/board_photo.png

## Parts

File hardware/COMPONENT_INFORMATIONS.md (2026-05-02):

# Technical Information — AR-488-ESP32 GPIB Interface

## Heltec WiFi Kit 32 (ESP32) — Complete Pinout

Board orientation: USB connector at bottom, OLED at top. 2x18 pin headers, 22.86mm row spacing.

### Left Row (top to bottom)

| Pos | Label | GPIO | Notes |
|-----|---|---|---|
| 1 | GND | -- | Power |
| 2 | 5V | -- | **5V output from USB** |
| 3 | 3V3 | -- | 3.3V output |
| 4 | RST | -- | Reset |
| 5 | 13 | GPIO13 | ADC2_4, Touch4 |
| 6 | 12 | GPIO12 | ADC2_5, Touch5 — strapping pin (LOW at boot) |
| 7 | 14 | GPIO14 | ADC2_6, Touch6 |
| 8 | 27 | GPIO27 | ADC2_7, Touch7 |
| 9 | 26 | GPIO26 | DAC2, ADC2_9 |
| 10 | 25 | GPIO25 | DAC1, ADC2_8 — on-board LED |
| 11 | 33 | GPIO33 | ADC1_5, Touch8 |
| 12 | 32 | GPIO32 | ADC1_4, Touch9 |
| 13 | 35 | GPIO35 | ADC1_7 — **input only** |
| 14 | 34 | GPIO34 | ADC1_6 — **input only** |
| 15 | 39 | GPIO39 | ADC1_3 — **input only** |
| 16 | 38 | GPIO38 | ADC1_2 — **input only** |
| 17 | 37 | GPIO37 | ADC1_1 — **input only** |
| 18 | 36 | GPIO36 | ADC1_0 — **input only** |

### Right Row (top to bottom)

| Pos | Label | GPIO | Notes |
|-----|---|---|---|
| 1 | GND | -- | Power |
| 2 | 5V | -- | **5V output from USB** |
| 3 | 3V3 | -- | 3.3V output |
| 4 | GND | -- | Power |
| 5 | TX | GPIO1 | U0_TXD — serial programming |
| 6 | RX | GPIO3 | U0_RXD — serial programming |
| 7 | 15 | GPIO15 | **OLED_SCL (reserved)** |
| 8 | 2 | GPIO2 | Strapping pin |
| 9 | 0 | GPIO0 | **PROG button**, strapping |
| 10 | 4 | GPIO4 | **OLED_SDA (reserved)** |
| 11 | 16 | GPIO16 | **OLED_RST (reserved)** |
| 12 | 17 | GPIO17 | U2_TXD |
| 13 | 5 | GPIO5 | V_SPI_CS0 — strapping pin |
| 14 | 18 | GPIO18 | V_SPI_CLK |
| 15 | 23 | GPIO23 | V_SPI_MOSI |
| 16 | 19 | GPIO19 | V_SPI_MISO |
| 17 | 22 | GPIO22 | I2C SCL |
| 18 | 21 | GPIO21 | I2C SDA, V_SPI_HD |

### GPIO Classification

**OLED reserved (3):** GPIO4 (SDA), GPIO15 (SCL), GPIO16 (RST)

**Input-only (6):** GPIO34, GPIO35, GPIO36, GPIO37, GPIO38, GPIO39

**Bidirectional, free for use (16):**
GPIO2, GPIO5, GPIO12, GPIO13, GPIO14, GPIO17, GPIO18, GPIO19, GPIO21, GPIO22, GPIO23, GPIO25, GPIO26, GPIO27, GPIO32, GPIO33

**Avoid:** GPIO0 (boot button), GPIO1 (TX), GPIO3 (RX), GPIO6-11 (internal flash)

### Sources
- Official pinout diagram: https://resource.heltec.cn/download/WiFi_Kit_32/WIFI%20Kit%2032_pinoutDiagram_V1.pdf
- Heltec documentation: https://docs.heltec.org/en/node/esp32/wifi_kit_32/index.html
- ESP32 GPIO reference: https://randomnerdtutorials.com/esp32-pinout-reference-gpios/

---

## Heltec WiFi Kit 32 V2 (ESP32) — Complete Pinout

Same ESP32-D0WDQ6 chip and 2x18 header layout as V1, but the V2 adds a **Vext** switchable 3.3V rail (controlled by GPIO21) and a battery voltage divider tied to GPIO13 (Power Detection). USB connector is still Micro-USB.

Board orientation: USB connector at bottom, OLED at top. 2x18 pin headers, 22.86mm row spacing.

### Left Row (top to bottom)

| Pos | Label | GPIO | Notes |
|-----|---|---|---|
| 1 | GND | -- | Power |
| 2 | 3V3 | -- | 3.3V output |
| 3 | Vext | -- | Switchable 3.3V (controlled by GPIO21) |
| 4 | RST | -- | Reset |
| 5 | 13 | GPIO13 | ADC2_4, Touch4 — **also tied to battery voltage divider (Power Detection)** |
| 6 | 12 | GPIO12 | ADC2_5, Touch5 — strapping pin (LOW at boot) |
| 7 | 14 | GPIO14 | ADC2_6, Touch6 |
| 8 | 27 | GPIO27 | ADC2_7, Touch7 |
| 9 | 26 | GPIO26 | DAC2, ADC2_9 |
| 10 | 25 | GPIO25 | DAC1, ADC2_8 — on-board LED |
| 11 | 33 | GPIO33 | ADC1_5, Touch8 |
| 12 | 32 | GPIO32 | ADC1_4, Touch9 |
| 13 | 35 | GPIO35 | ADC1_7 — **input only** |
| 14 | 34 | GPIO34 | ADC1_6 — **input only** |
| 15 | 39 | GPIO39 | ADC1_3 — **input only** |
| 16 | 38 | GPIO38 | ADC1_2 — **input only** |
| 17 | 37 | GPIO37 | ADC1_1 — **input only** |
| 18 | 36 | GPIO36 | ADC1_0 — **input only** |

### Right Row (top to bottom)

| Pos | Label | GPIO | Notes |
|-----|---|---|---|
| 1 | GND | -- | Power |
| 2 | 5V | -- | **5V output from USB** |
| 3 | 3V3 | -- | 3.3V output |
| 4 | Vext | -- | Switchable 3.3V |
| 5 | TX | GPIO1 | U0_TXD — serial programming |
| 6 | RX | GPIO3 | U0_RXD — serial programming |
| 7 | 15 | GPIO15 | **OLED_SCL (reserved)** |
| 8 | 2 | GPIO2 | Strapping pin |
| 9 | 0 | GPIO0 | **PRG button**, strapping |
| 10 | 4 | GPIO4 | **OLED_SDA (reserved)** |
| 11 | 16 | GPIO16 | **OLED_RST (reserved)** |
| 12 | 17 | GPIO17 | U2_TXD |
| 13 | 5 | GPIO5 | V_SPI_CS0 — strapping pin |
| 14 | 18 | GPIO18 | V_SPI_CLK |
| 15 | 23 | GPIO23 | V_SPI_MOSI |
| 16 | 19 | GPIO19 | V_SPI_MISO |
| 17 | 22 | GPIO22 | I2C SCL |
| 18 | 21 | GPIO21 | I2C SDA — **also Vext control** (drive HIGH to enable Vext rail) |

### Differences vs V1

- Vext switchable 3.3V rail added — left pos 3 and right pos 4 (V1 had `3V3` and `GND` there)
- GPIO21 doubles as Vext enable (drive HIGH to power Vext) — careful when using as I2C SDA
- GPIO13 has a battery voltage divider on it (Power Detection) — usable as GPIO but reads ~½·VBAT when battery is connected
- USB chip changed from CP2102 to CP2104 in some revs (still Micro-USB)

### GPIO Classification (same as V1)

**OLED reserved (3):** GPIO4 (SDA), GPIO15 (SCL), GPIO16 (RST)
**Input-only (6):** GPIO34, GPIO35, GPIO36, GPIO37, GPIO38, GPIO39
**Bidirectional, free for use (16):** GPIO2, GPIO5, GPIO12, GPIO13, GPIO14, GPIO17, GPIO18, GPIO19, GPIO21, GPIO22, GPIO23, GPIO25, GPIO26, GPIO27, GPIO32, GPIO33
**Avoid:** GPIO0 (boot button), GPIO1 (TX), GPIO3 (RX), GPIO6-11 (internal flash)

### Sources
- Official pinout diagram: https://resource.heltec.cn/download/WiFi_Kit_32/WIFI_Kit_32_pinoutDiagram_V2.pdf
- Heltec hardware update log: https://wiki.heltec.org/docs/devices/open-source-hardware/esp32-series/lora-32/wifi-kit-32/hardware_update_log

---

## Heltec WiFi Kit 32 V3 (ESP32-S3) — Complete Pinout

**Major architectural change:** V3 uses **ESP32-S3FN8** (Xtensa LX7 dual-core, 8 MB flash) instead of the original ESP32. USB is now **Type-C** with native USB support on the S3 (CP2102 still present for serial). Different GPIO numbering — V1/V2 firmware will NOT run unmodified.

Board orientation: USB connector at top, OLED below. 2x18 pin headers (Heltec calls them **J2** = left, **J3** = right), 2.54mm pitch.

### Left Row — Header J2 (top to bottom)

| Pos | Label | GPIO | Notes |
|-----|---|---|---|
| 1 | GND | -- | Power |
| 2 | 5V | -- | **5V output from USB** (max 500 mA) |
| 3 | Ve | -- | Vext switchable 3.3V (controlled by GPIO36, max 350 mA) |
| 4 | Ve | -- | Vext switchable 3.3V (second pin) |
| 5 | RX | GPIO44 | U0_RXD — connected to CP2102 TXD |
| 6 | TX | GPIO43 | U0_TXD — connected to CP2102 RXD |
| 7 | RST | -- | CHIP_PU (reset switch) |
| 8 | 0 | GPIO0 | **PRG button**, strapping |
| 9 | 21 | GPIO21 | **OLED_RST (reserved)** |
| 10 | 20 | GPIO20 | U1_CTS, ADC2_CH9, CLK_OUT1, **USB_D+** (solder R29 to connect to USB socket) |
| 11 | 19 | GPIO19 | U1_RTS, ADC2_CH8, CLK_OUT2, **USB_D−** (solder R3 to connect to USB socket) |
| 12 | 7 | GPIO7 | ADC1_CH6, Touch7 |
| 13 | 6 | GPIO6 | ADC1_CH5, Touch6 |
| 14 | 5 | GPIO5 | ADC1_CH4, Touch5 |
| 15 | 4 | GPIO4 | ADC1_CH3, Touch4 |
| 16 | 3 | GPIO3 | ADC1_CH2, Touch3 |
| 17 | 2 | GPIO2 | ADC1_CH1, Touch2 |
| 18 | 1 | GPIO1 | ADC1_CH0, Touch1 — **also tied to VBAT divider** (V_BAT = (100+390)/100 · V_ADC) |

### Right Row — Header J3 (top to bottom)

| Pos | Label | GPIO | Notes |
|-----|---|---|---|
| 1 | GND | -- | Power |
| 2 | 3V3 | -- | 3.3V output (max 500 mA) |
| 3 | 3V3 | -- | 3.3V output |
| 4 | 26 | GPIO26 | SPICS1 |
| 5 | 48 | GPIO48 | SPICLK_N_DIFF, SUBSPICLK_N_DIFF |
| 6 | 47 | GPIO47 | SPICLK_P_DIFF, SUBSPICLK_P_DIFF |
| 7 | 33 | GPIO33 | SPIIO4, FSPIHD, SUBSPIHD |
| 8 | 34 | GPIO34 | SPIIO5, FSPICS0, SUBSPICS0 |
| 9 | 35 | GPIO35 | SPIIO6, FSPID, SUBSPID — **on-board LED control** |
| 10 | 36 | GPIO36 | SPIIO7, FSPICLK, SUBSPICLK — **Vext enable (drive HIGH to power Vext)** |
| 11 | 37 | GPIO37 | SPIDQS, FSPIQ, SUBSPIQ — **ADC_Ctrl (battery measurement enable)** |
| 12 | 38 | GPIO38 | FSPIWP, SUBSPIWP |
| 13 | 39 | GPIO39 | MTCK (JTAG) |
| 14 | 40 | GPIO40 | MTDO (JTAG) |
| 15 | 41 | GPIO41 | MTDI (JTAG) |
| 16 | 42 | GPIO42 | MTMS (JTAG) |
| 17 | 45 | GPIO45 | strapping pin (VDD_SPI voltage select) |
| 18 | 46 | GPIO46 | strapping pin (boot mode) |

### On-Board Peripherals (NOT broken out to headers)

- **OLED I2C:** GPIO17 = OLED_SDA, GPIO18 = OLED_SCL (internal — do not reuse). OLED_RST = GPIO21 (this one IS on the header, J2 pos 9).
- **CP2102 USB-serial:** GPIO43/44 (also broken out at J2 pos 5/6).

### Differences vs V1/V2

- **MCU:** ESP32-S3 (LX7, 8 MB flash, native USB) — different SDK requirements; firmware is not binary-compatible with V1/V2.
- **USB:** Type-C (was Micro-USB).
- **Deep sleep:** <10 µA (was ~800 µA on V2).
- **No DAC** on ESP32-S3 (V1/V2 had DAC1/DAC2 on GPIO25/26).
- **No "input-only" pins** on ESP32-S3 (all broken-out GPIOs are bidirectional).
- **OLED I2C bus moved internal** — V1/V2 reserved GPIO4/GPIO15 (broken-out pins); V3 uses GPIO17/GPIO18 internally and frees the corresponding header positions for general use.
- **LED moved** from GPIO25 (V1/V2) to GPIO35 (V3).
- **Vext control moved** from GPIO21 (V2) to GPIO36 (V3); GPIO21 is now OLED_RST instead.
- **Battery sense moved** from GPIO13 (V2) to GPIO1 (V3), gated by GPIO37 (ADC_Ctrl).
- **Strapping pins:** GPIO0, GPIO45, GPIO46 (different from ESP32 strapping set).

### GPIO Classification

**OLED-reserved (internal, do not reuse):** GPIO17, GPIO18
**OLED RST (header, reserved if using on-board OLED):** GPIO21
**Programming UART (avoid for general use):** GPIO43 (TX), GPIO44 (RX)
**Boot/strapping (use with care):** GPIO0, GPIO45, GPIO46
**USB D+/D− (only connected to USB socket if R29/R3 soldered):** GPIO20, GPIO19
**On-board LED:** GPIO35
**Vext enable:** GPIO36
**ADC enable for battery sense:** GPIO37
**Battery voltage:** GPIO1 (still usable as GPIO/touch/ADC otherwise)
**Free for general use (broken out):** GPIO2, GPIO3, GPIO4, GPIO5, GPIO6, GPIO7, GPIO19, GPIO20, GPIO26, GPIO33, GPIO34, GPIO38, GPIO39, GPIO40, GPIO41, GPIO42, GPIO47, GPIO48

### Sources
- Official datasheet (HTIT-WB32_V3 Rev 1.1): https://resource.heltec.cn/download/WiFi_Kit_32_V3/HTIT-WiFi%20kit32_V3(Rev1.1).pdf
- Product page: https://heltec.org/project/wifi-kit32-v3/
- ESP32-S3 datasheet: https://www.espressif.com/sites/default/files/documentation/esp32-s3_datasheet_en.pdf

---

## SN75160BDW — GPIB Data Bus Transceiver (SOIC-20)

KiCad symbol: `Interface:SN75160BDW`
KiCad footprint: `Package_SO:SOIC-20W_7.5x12.8mm_P1.27mm`

### Pinout

| Pin | Name | Function |
|-----|---|---|
| 1 | TE | Talk Enable (input) — HIGH=transmit, LOW=receive |
| 2 | B1 | GPIB bus DIO1 |
| 3 | B2 | GPIB bus DIO2 |
| 4 | B3 | GPIB bus DIO3 |
| 5 | B4 | GPIB bus DIO4 |
| 6 | B5 | GPIB bus DIO5 |
| 7 | B6 | GPIB bus DIO6 |
| 8 | B7 | GPIB bus DIO7 |
| 9 | B8 | GPIB bus DIO8 |
| 10 | GND | Ground |
| 11 | ~{PE} | Pull-up Enable (input) — active LOW. Tie to VCC for 3-state mode |
| 12 | D8 | Terminal DIO8 (MCU side) |
| 13 | D7 | Terminal DIO7 |
| 14 | D6 | Terminal DIO6 |
| 15 | D5 | Terminal DIO5 |
| 16 | D4 | Terminal DIO4 |
| 17 | D3 | Terminal DIO3 |
| 18 | D2 | Terminal DIO2 |
| 19 | D1 | Terminal DIO1 |
| 20 | VCC | +5V supply (4.75-5.25V) |

**Notes:** D-side pins are in reverse order (D8=pin12, D1=pin19). B-side (bus) is B1=pin2 to B8=pin9.

### Source
- TI Datasheet: https://www.ti.com/lit/ds/symlink/sn75160b.pdf

---

## SN75161BN — GPIB Control Bus Transceiver (DIP-20)

**Not in KiCad 9.0 standard library — custom symbol required.**

### Pinout

| Pin | Name | Function |
|-----|---|---|
| 1 | TE | Talk Enable (input) — controls DAV, NRFD, NDAC direction |
| 2 | REN (bus) | Remote Enable — GPIB bus side |
| 3 | IFC (bus) | Interface Clear — GPIB bus side |
| 4 | NDAC (bus) | Not Data Accepted — GPIB bus side |
| 5 | NRFD (bus) | Not Ready For Data — GPIB bus side |
| 6 | DAV (bus) | Data Valid — GPIB bus side |
| 7 | EOI (bus) | End Or Identify — GPIB bus side |
| 8 | ATN (bus) | Attention — GPIB bus side |
| 9 | SRQ (bus) | Service Request — GPIB bus side |
| 10 | GND | Ground |
| 11 | DC | Direction Control (input) — controls ATN, SRQ, REN, IFC direction |
| 12 | SRQ (term) | Service Request — terminal/MCU side |
| 13 | ATN (term) | Attention — terminal side |
| 14 | EOI (term) | End Or Identify — terminal side |
| 15 | DAV (term) | Data Valid — terminal side |
| 16 | NRFD (term) | Not Ready For Data — terminal side |
| 17 | NDAC (term) | Not Data Accepted — terminal side |
| 18 | IFC (term) | Interface Clear — terminal side |
| 19 | REN (term) | Remote Enable — terminal side |
| 20 | VCC | +5V supply (4.75-5.25V) |

**Direction control:**
- TE controls direction of DAV, NRFD, NDAC
- DC controls direction of ATN, SRQ, REN, IFC
- EOI direction controlled by TE AND DC jointly

### Source
- TI Datasheet: https://www.ti.com/lit/ds/symlink/sn75161b.pdf

---

## GPIB IEEE-488 Centronics 24-Pin Connector Pinout

| Pin | Signal | Type | Pin | Signal | Type |
|-----|---|---|-----|---|---|
| 1 | DIO1 | Data | 13 | DIO5 | Data |
| 2 | DIO2 | Data | 14 | DIO6 | Data |
| 3 | DIO3 | Data | 15 | DIO7 | Data |
| 4 | DIO4 | Data | 16 | DIO8 | Data |
| 5 | EOI | Management | 17 | REN | Management |
| 6 | DAV | Handshake | 18 | GND (DAV ret) | Ground |
| 7 | NRFD | Handshake | 19 | GND (NRFD ret) | Ground |
| 8 | NDAC | Handshake | 20 | GND (NDAC ret) | Ground |
| 9 | IFC | Management | 21 | GND (IFC ret) | Ground |
| 10 | SRQ | Management | 22 | GND (SRQ ret) | Ground |
| 11 | ATN | Management | 23 | GND (ATN ret) | Ground |
| 12 | SHIELD | Ground | 24 | GND (Logic) | Ground |

**Ground pins:** 12, 18, 19, 20, 21, 22, 23, 24

### Source
- IEEE 488.1 standard
- NI GPIB concepts: https://www.ni.com/docs/en-US/bundle/gpib-help/page/gpib-concepts/gpib_concepts.html

---

## MCP23017 — I2C 16-bit GPIO Expander

KiCad symbol: `Interface_Expansion:MCP23017_SO` (SOIC-28)
KiCad footprint: `Package_SO:SOIC-28W_7.5x17.9mm_P1.27mm`

- **I2C speed:** up to 1.7 MHz
- **VCC range:** 1.8V–5.5V (works at 3.3V)
- **Outputs:** 25mA push-pull per pin
- **Interrupt:** per-pin configurable, active-low/high or open-drain
- **Address pins:** A0, A1, A2 — up to 8 devices on one bus (base address 0x20)
- **Latency:** ~20µs per byte at 1 MHz I2C

### Source
- Microchip datasheet: https://ww1.microchip.com/downloads/en/DeviceDoc/20001952C.pdf

---

## Tektronix TDS784A — GPIB Performance

- **GPIB standard:** IEEE-488.2, supports HS488
- **Transfer rate:** 200–500 KB/s sustained (standard mode), up to 1.2 MB/s with HS488
- **Handshake cycle:** 2–5 µs (standard), 1–2 µs (HS488)
- **Classification:** Fast GPIB instrument (NOT slow despite some claims)
- **HS488 T1:** 350 ns minimum

### Source
- Tek programmer manual: https://www.tek.com/en/manual/tds784a-tds784c-tds784d-programmer-manual
- NI HS488: https://www.ni.com/docs/en-US/bundle/gpib-help/page/gpib-concepts/hs488-protocol.html

---

## Architecture Decision: Hybrid GPIO + MCP23017

### Signal Split

**Direct ESP32 GPIOs (fast path — 15 signals):**
- DIO1–DIO8 (8 data lines) — change every byte
- DAV, NRFD, NDAC (3 handshake lines) — change every byte
- EOI (1 line) — end-of-message detection
- TE_data (1 line) — SN75160B talk enable
- I2C SDA, SCL (2 lines) — for MCP23017

**MCP23017 (slow path — 5 signals, accessed only on mode changes):**
- ATN — once per command sequence
- IFC — once per session (bus reset)
- SRQ — occasional polling
- REN — once per session
- TE_ctrl (SN75161B talk enable)
- DC (SN75161B direction control)

**Total ESP32 GPIOs used: 15** (13 signals + 2 I2C). Available: 16. **1 spare.**

**Result:** Zero I2C overhead during data transfer. Full TDS784A speed preserved.

---

## Reverse Polarity Protection — P-FET (AO3401A)

Instead of a Schottky diode (~300mV drop), use a P-channel MOSFET for near-zero dropout protection.

**Selected part: AO3401A** (SOT-23)
- Vds: -30V (plenty of margin for 12V input)
- Rds(on): 60mΩ typ @ Vgs=-10V; ~75mΩ @ Vgs=-4.5V
- Vgs(th): -0.4V to -1.1V (logic-level)
- Vgs max: **±12V** — at 12V input this is right at the limit; add a Zener clamp (e.g. 10V) Gate↔Source if input may exceed 12V
- Id: -4A continuous (limited by SOT-23 package thermals)
- Voltage drop @ 200mA: **~15mV** (vs ~300mV for Schottky — still excellent)
- Package: SOT-23 (pin 1 = Gate, pin 2 = Source, pin 3 = Drain)
- KiCad symbol: **custom required** (not in KiCad 9.0 standard library — generic `Device:Q_PMOS_GSD` works as a stand-in)
- Datasheet: https://www.aosmd.com/res/datasheets/AO3401A.pdf

**Circuit:**
- Source → barrel jack V+ (7-12V)
- Drain → AMS1117-5.0 VIN
- Gate → GND via 100kΩ pull-down resistor (R_gate)

**How it works:** Normal polarity: Vgs is large negative → FET fully on, millivolt drop. Reverse polarity: Vgs ≥ 0 → FET off, body diode reverse-biased, no current flows.

### Sources
- AO3401A datasheet: https://www.aosmd.com/sites/default/files/res/datasheets/AO3401A.pdf
- Design guide: https://components101.com/articles/design-guide-pmos-mosfet-for-reverse-voltage-polarity-protection

---

## KiCad Component Summary

| Component | KiCad Symbol | KiCad Footprint | In Std Library? |
|---|---|---|---|
| SN75160BDW | `Interface:SN75160BDW` | `Package_SO:SOIC-20W_7.5x12.8mm_P1.27mm` | Yes |
| SN75161BN | **Custom required** | `Package_DIP:DIP-20_W7.62mm` | No |
| AMS1117-5.0 | `Regulator_Linear:AMS1117-5.0` | `Package_TO_SOT_SMD:SOT-223-3_TabPin2` | Yes |
| MCP23017 (SOIC) | `Interface_Expansion:MCP23017_SO` | `Package_SO:SOIC-28W_7.5x17.9mm_P1.27mm` | Yes |
| Barrel Jack | `Connector:Barrel_Jack` | `Connector_BarrelJack:BarrelJack_Horizontal` | Yes |
| 2x18 pin header | `Connector_Generic:Conn_02x18_Odd_Even` | custom (22.86mm spacing) | Symbol yes |
| 2x12 connector | `Connector_Generic:Conn_02x12_Odd_Even` | custom (Centronics 24) | Symbol yes |
| AO3401A (P-FET) | **Custom required** | `Package_TO_SOT_SMD:SOT-23` | No |
| Cap 0805 | `Device:C` | `Capacitor_SMD:C_0805_2012Metric` | Yes |
| Cap 0603 | `Device:C` | `Capacitor_SMD:C_0603_1608Metric` | Yes |
| Resistor 0603 | `Device:R` | `Resistor_SMD:R_0603_1608Metric` | Yes |

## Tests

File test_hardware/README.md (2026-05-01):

# GPIB pin test firmware

Boot-then-loop sketch that pulses every GPIB connector pin HIGH for 1 ms in
connector pin-number order, with the SN75160B / SN75161B transceivers held
in the correct direction so each pulse propagates to the bus side.

Used to verify the AR-488-ESP32 board on a scope: probe any GPIB pin and you
should see a 1 ms pulse roughly 50× per second.

## Layout

- `platformio.ini` — two PIO envs:
  - `heltec_wifi_kit_32` (V1, 26 MHz xtal — current physical board)
  - `heltec_wifi_kit_32_v2` (V2, 40 MHz xtal)
- `src/main.cpp` — single-file Arduino sketch.
- `docs/a_faire.md` — original spec.

## Build & flash

```bash
~/.platformio/penv/Scripts/pio.exe run \
  -d firmware/test -e heltec_wifi_kit_32 \
  -t upload --upload-port COM6
```

Serial monitor: 115200 baud.

## Pin sweep

Each loop iteration pulses these signals in this order, then idles for
`CYCLE_MS = 20 ms`:

| GPIB pin | Signal | Source |
|---:|---|---|
| 1 | DIO1 | ESP32 GPIO13 |
| 2 | DIO2 | ESP32 GPIO12 |
| 3 | DIO3 | ESP32 GPIO14 |
| 4 | DIO4 | ESP32 GPIO27 |
| 5 | EOI | ESP32 GPIO19 |
| 6 | DAV | ESP32 GPIO5  |
| 7 | NRFD | ESP32 GPIO18 |
| 8 | NDAC | ESP32 GPIO23 |
| 9 | IFC | MCP23017 GPA1 |
| 10 | SRQ | MCP23017 GPA2 |
| 11 | ATN | MCP23017 GPA0 |
| 13 | DIO5 | ESP32 GPIO26 |
| 14 | DIO6 | ESP32 GPIO25 |
| 15 | DIO7 | ESP32 GPIO33 |
| 16 | DIO8 | ESP32 GPIO32 |
| 17 | REN | MCP23017 GPA3 |

The 12 direct-GPIO signals (data + handshake + EOI) toggle in zero time;
the 4 MCP23017 signals (management) go through an I2C write at 400 kHz.

## Transceiver direction control

The part that took the most iteration to get clean pulses on the bus side:

- `TE_DATA = HIGH` (GPIO17) — SN75160B in Talk for DIO1..8. Held the entire run.
- `TE_CTRL = HIGH` (MCP GPA4) — SN75161B handshake in Talk. Set once at
  startup, **never flipped** during the sweep.
- `DC = LOW` (MCP GPA5) — SN75161B management in **controller** direction
  (drives ATN/IFC/REN out, listens for SRQ).
- `DC` is pulsed HIGH **only** around the SRQ pulse, with 1 ms settle
  margins on each side, so SRQ is driven outward as a "device". DC returns
  to LOW for the rest of the sweep.

### Why DC flips and TE_CTRL doesn't

We tried dropping TE_CTRL on individual pulses (e.g. during NDAC / NRFD,
during SRQ). It produced coupling artefacts on neighbouring lines: the
SN75161B's internal direction logic decodes per signal-group, so changing
TE_CTRL re-routes multiple pins at once and ghost edges show up
elsewhere. Keeping TE_CTRL fixed and only toggling DC around SRQ matches
what real GPIB device-mode traffic looks like and produced clean per-pin
pulses on the bus side.

## Other notable bits

- `setup()` drives every direct GPIO LOW before enabling outputs, so
  GPIO12 (= DIO2, an ESP32 boot-strap pin that must be LOW at reset for
  3.3 V flash) is safe at power-up.
- MCP23017 GPIOB is set to outputs and forced LOW (not floating inputs)
  to avoid shoot-through inside the chip.
- I2C is 400 kHz on SDA = GPIO21 / SCL = GPIO22. External pull-ups on the
  board are required — the ESP32 internal pulls (~45 kΩ) are too weak for
  reliable 400 kHz operation.
- If the MCP23017 doesn't ACK at 0x20, the firmware prints a warning and
  silently no-ops the MCP writes (direct-GPIO pulses still work).

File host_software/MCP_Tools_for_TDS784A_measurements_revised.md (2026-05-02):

# MCP Tools for TDS784A Measurements — Revised Proposal

This document specifies the MCP server that lets an AI drive a Tektronix
TDS784A through the AR-488-ESP32 GPIB gateway. It supersedes
`MCP_Tools_for_TDS784_measurements.md`.

## Goals

1. Let the AI characterize a circuit (single measurements, swept measurements,
   waveform capture, screenshots) without forcing it to write SCPI.
2. Let the AI save a setup before experimenting and restore it on demand —
   "try-this-and-revert" workflows.
3. Make incoherent multi-channel reads impossible (atomic single-shot capture).
4. Surface scope errors after every write — no silent failures.
5. Stay close to the metal where it matters: an `raw_scpi` escape hatch and
   a clear path to add Phase 2 features (FFT/MATH, REFs, persistence, advanced
   triggers) without redesign.

## Architecture

```
  Claude  <-stdio->  MCP server (Python, FastMCP)
                          |
                          | reuses request_gpib.py as a library
                          v
                     WebSocket to ws://<host>/ws
                          |
                          v
                     AR-488-ESP32 gateway
                          |
                          v
                     GPIB bus -> TDS784A
```

- One persistent WebSocket connection for the server lifetime, with a
  single `asyncio.Lock` around send/recv. No reconnect logic — if the WS
  drops the user restarts the MCP server.
- Connection params come from env vars: `AR488_HOST` (required), `AR488_ADDR`
  (default 1), `AR488_TIMEOUT_MS` (default 2000).
- No caching. `*IDN?` and `SET?` are queried each time they're asked for.
- All I/O primitives (`one_shot`, `parse_ieee_block`, `parse_wfmpre`,
  `query_value`, `_setup_channel`, `_set_window`, `capture_channel`,
  `pcx_bytes_to_png`, …) are imported from `request_gpib.py`. Each consumed
  symbol is annotated in `request_gpib.py` with a comment warning that
  signature changes will break the MCP server. The CLI surface of
  `request_gpib.py` is free to evolve; the library surface is not.
- Hardcopy returns an inline MCP `image` content block (PNG) so Claude can
  *see* the screen, plus the bytes themselves for file persistence.

## Cross-cutting policies

### Error draining
After every command that changes scope state, the server queries `*ESR?` and
`ALLEv?` and surfaces any non-zero result as a structured error in the tool
response (alongside the success payload, not as an exception, so the AI can
read both). A read-only query never drains errors implicitly — there's a
dedicated `get_errors` tool.

### Units
Returned values are always SI (volts, seconds, hertz, ohms). Raw ADC codes
aren't exposed in v1 — `raw_scpi("CURVE?", binary=True)` is the escape hatch
if ever needed.

### Atomic multi-channel capture
`get_waveform(channels=[…])` performs one single-sequence acquisition and
reads all requested channels from that record. CH1 and CH2 are guaranteed to
share the same trigger event.

### Destructive-action guard
Two tools are gated behind an explicit `confirm=True` argument:
- `factory_reset` (FACtory) — wipes all NVRAM setups; the user wants to
  exercise this manually before trusting it.
- `set_setup_state` (sending an arbitrary SET? string back) — does **not**
  require a prior `factory_reset`; the AI may trust a previously captured
  state.

`*RST` is not exposed as a separate tool — `set_setup_state` covers
"restore a known good", and `factory_reset` covers "panic button".

### Statistics — two flavors, both exposed
The TDS784A firmware has **no** measurement-statistics SCPI group (no
running mean/min/max/stddev across acquisitions). Two compatible alternatives
are offered, and the AI is told what each one really computes:

- **Acquisition-level statistics** (`measure_with_acq_stats`): set the scope
  to `ACQUIRE:MODE AVERAGE` (or `ENVELOPE`) with N acquisitions, then take
  one measurement of the resulting smoothed/enveloped waveform. Fast, only
  one MEASUREMENT? at the end. Appropriate for *steady* signals where you
  want noise-free amplitude/timing readings. Cannot give you stddev — only
  the central tendency (AVERAGE) or the worst-case excursion (ENVELOPE).
- **Polled per-acquisition statistics** (`measure_with_polled_stats`): leave
  the scope in SAMPLE mode and poll `MEASUREMENT:IMMED:VALUE?` over N
  separate triggers. Aggregate mean/min/max/stddev/p5/p95 client-side.
  Slower (N round-trips), but answers questions about *jitter*, *drift*,
  and *distribution* that AVERAGE/ENVELOPE cannot.

Documenting this difference is part of the tool description so the AI picks
the right one.

---

# Phase 1 — v1 tool surface

~18 tools across 7 groups. Anything more obscure goes through `raw_scpi`.

## 1. Connection & status

### `verify_instrument_identity`
- SCPI: `*IDN?`
- Returns: `{vendor, model, serial, firmware}`.

### `get_errors`
- SCPI: `*ESR?` then `ALLEv?` (drain queue)
- Returns: list of `{code, message}` plus the raw ESR byte.

### `wait_operation_complete(timeout_s=10)`
- SCPI: `*OPC?` with polling
- Returns: `{ok: bool, elapsed_s}`. Used internally by single-shot capture;
  exposed for the AI to use after `set_setup_state` or large changes.

## 2. Setup state management

### `get_setup_state()`
- SCPI: `HEADER ON; SET?`
- Returns: `{setup_string, idn, captured_at}`.

### `set_setup_state(setup_string, confirm=False)`
- Sends the string verbatim, then `*OPC?`, then drains errors.
- **Refuses unless `confirm=True`.**
- Does **not** require a prior factory reset.

### `save_internal(slot)`
- SCPI: `*SAV <1..10>`

### `recall_internal(slot)`
- SCPI: `*RCL <1..10>`. Drains errors.

### `factory_reset(confirm=False)`
- SCPI: `FACtory`
- **Refuses unless `confirm=True`.** Most disruptive tool; user will
  validate it manually before trusting it.

## 3. Acquisition control

### `autoset()`
- SCPI: `AUTOSet EXECute`, then `*OPC?`.

### `set_acquisition_mode(mode)`
- mode ∈ `{SAMPLE, PEAKDETECT, HIRES, ENVELOPE, AVERAGE}`
- SCPI: `ACQUIRE:MODE <mode>`

### `set_average_count(n)` — n ∈ {2,4,8,…,10000}
- SCPI: `ACQUIRE:NUMAVG <n>`. Envelope count via `raw_scpi` if needed.

### `set_acquisition_state(state)` — state ∈ {RUN, STOP}
- SCPI: `ACQUIRE:STATE <state>`

### `arm_single_and_wait(timeout_s=30)` — atomic
- Sequence: `ACQUIRE:STOPAFTER SEQUENCE; ACQUIRE:STATE RUN; *OPC?`
- Returns when the scope reports OPC, or errors on timeout.
- This is the building block the AI uses to guarantee fresh data.

## 4. Vertical / horizontal / trigger setup

### `set_vertical(ch, scale_v=None, position_div=None, offset_v=None, coupling=None, bandwidth=None, impedance=None, probe_atten=None, units=None, deskew_s=None, invert=None)`
- Sends only the sub-commands whose argument is provided.
- Key SCPI: `CHx:SCALE`, `CHx:POSITION`, `CHx:OFFSET`, `CHx:COUPLING`,
  `CHx:BANDWIDTH`, `CHx:IMPEDANCE`, `CHx:PROBE`, `CHx:UNITS`, `CHx:DESKEW`,
  `CHx:INVERT`.
- Position vs. offset distinction is documented in the tool description.
- Channel on/off via `raw_scpi("SELECT:CH<n> ON|OFF")` if needed.

### `set_horizontal(scale_s=None, position_pct=None, record_length=None)`
- SCPI: `HORIZONTAL:MAIN:SCALE`, `HORIZONTAL:TRIGGER:POSITION`,
  `HORIZONTAL:RECORDLENGTH`.

### `set_trigger_edge(source=None, level_v=None, slope=None, coupling=None, holdoff_s=None, mode=None)`
- mode ∈ {AUTO, NORMAL}; slope ∈ {RISE, FALL}.
- SCPI: `TRIGGER:MAIN:TYPE EDGE` then `TRIGGER:MAIN:EDGE:*` and
  `TRIGGER:MAIN:LEVEL` / `:HOLDOFF:VALUE` / `:MODE`.
- v1 only covers edge triggers. Pulse/logic/runt/glitch are Phase 2.

### `get_acquisition_setup()`
- Single tool that returns the full read-only setup snapshot used by
  `request_gpib.py`'s `collect_metadata`: horizontal, trigger, acquire,
  per-channel state. Convenient for "save my context" without a full SET?.

## 5. Measurements

### `measure(ch, kind, source2=None)`
- Uses **immediate** measurements (`MEASUREMENT:IMMED`) so the on-screen
  MEAS1..4 slots are not disturbed.
- `kind` is one of the 25 supported types: AMPL, FREQ, PERIOD, RISE, FALL,
  PK2PK, MEAN, RMS, CRMS, DUTY, … delay-type measurements take `source2`.
- SCPI: `MEASUREMENT:IMMED:TYPE <kind>; SOURCE1 CHx; SOURCE2 CHy; VALUE?; UNITS?`
- Returns: `{value, unit, kind, source, source2}`.

### `measure_snapshot(ch)`
- SCPI: `MEASUREMENT:IMMED:SOURCE1 CHx; SNAPSHOT?`
- Returns: dict of all 25 measurements with units. One round-trip.

### `set_measurement_ref_levels(method=None, high=None, mid=None, low=None, mid2=None, units=None)`
- `method` ∈ {ABSolute, PERCent}; `units` ∈ {V, %}.
- SCPI: `MEASUREMENT:REFLEVEL:METHOD`,
  `MEASUREMENT:REFLEVEL:{ABS,PERC}:{HIGH,MID,LOW,MID2}`.
- Affects how rise/fall/duty are computed.
- Measurement gating (rare) is left to `raw_scpi`.

### `measure_with_acq_stats(ch, kind, mode='AVERAGE', count=64, source2=None)`
- Acquisition-level stats. Sets `ACQUIRE:MODE <mode>`, `NUMAVG/NUMENV count`,
  arms single-sequence, waits for OPC, takes one immediate measurement.
- Returns: `{value, unit, mode, count}`. With `mode=ENVELOPE` runs twice
  (one min, one max) — documented.

### `measure_with_polled_stats(ch, kind, n=32, source2=None, max_wall_s=30)`
- Polled per-acquisition stats. Loops `arm_single_and_wait` then
  `MEASUREMENT:IMMED:VALUE?` n times.
- Returns: `{n, mean, std, min, max, p5, p95, samples?}`.
- Slow; bounded by `max_wall_s`.

## 6. Waveform retrieval

### `get_waveform(channels, start_idx=None, end_idx=None, width=2)`
- Atomic multi-channel single-shot. Sequence:
  1. `ACQUIRE:STOPAFTER SEQUENCE; ACQUIRE:STATE RUN; *OPC?`
  2. For each channel: `DATA:SOURCE CHx`, `WFMPRE?`, `CURVE?`
  3. Convert raw codes → volts using preamble.
- Default `width=2` for full 16-bit fidelity (current CLI default is 1).
- Returns:
  ```
  {
    metadata: { … same shape as collect_metadata … },
    channels: {
      "CH1": { time_s: [...], voltage_v: [...], preamble: {…} },
      ...
    },
    start_idx, end_idx, samples_per_channel
  }
  ```
- Windowing via `start_idx`/`end_idx` (1-based inclusive), maps to
  DATA:START / DATA:STOP. Auto-chunking handled internally if window > 32 KiB.

## 7. Screen capture

### `get_screen(layout='PORTRAIT', palette='COLOR')`
- HARDCOPY sequence (PCXCOLOR → PNG client-side).
- Returns:
  - MCP `image` content block (PNG bytes inline) so the AI can see the
    screen visually.
  - Plus `{format: 'PNG', bytes_len, source_format: 'PCXCOLOR'}` metadata.
- Caller may choose to save the bytes; the MCP does not write a file by
  default.

## 8. Escape hatch (the safety valve for everything trimmed)

### `raw_scpi(command, expect_reply=None, binary=False, timeout_ms=None)`
- `expect_reply=None` autodetects from `?` in command (mirrors current CLI).
- `expect_reply=True` issues a `query` (or `binary_query` if `binary`).
- `expect_reply=False` issues a write.
- All traffic is logged. Drains errors after writes.
- Documented as the "anything I forgot" hatch.

---

# Phase 2 — deferred

Add when v1 is stable. Each is roughly one tool group.

| Group | Tools | Notes |
|---|---|---|
| Math waveforms | `define_math(slot, expr)`, `get_math_waveform(slot, …)` | Slot ∈ MATH1..3. Expr supports `CH1+CH2`, `CH1-CH2`, `FFT(CH1)`, etc. FFT requires the optional Advanced DSP firmware (verify on this unit). |
| Reference waveforms | `save_to_ref(slot, source)`, `recall_ref(slot)`, `get_ref_waveform(slot)` | REF1..4 in NVRAM. |
| Display persistence | `set_persistence(mode, time_s=None)` | INFINITE / VARIABLE / OFF. Killer feature for glitch hunting. |
| Advanced triggers | `set_trigger_pulse(...)`, `set_trigger_glitch(...)`, `set_trigger_runt(...)`, `set_trigger_logic(...)`, `set_trigger_video(...)` | One tool per trigger type to keep schemas tight. |
| Cursor measurements | Likely **skipped** in favor of client-side compute against captured waveforms. Re-evaluate. |
| Limit testing | `set_limit_test(template_ref, vert_tol_div, horiz_tol_div)`, `get_limit_status()` | Template-based pass/fail. |
| Higher-level intent tools | `characterize_channel(ch)`, `compare_to_reference(ch, ref)`, `sweep_and_measure(...)`, `find_anomaly(ch, duration_s)` | Compose Phase 1 primitives. |
| Calibration status | `get_calibration_status()` | `CAL?`, `CAL:TEMP?`. |

---

# Skill: `/scope`

A short Claude Code skill (`~/.claude/skills/scope.md`) that triggers on
"TDS784", "oscilloscope", etc. Documents the v1 tool surface, the
AVERAGE-vs-polled stats trade-off, the confirm-required tools, and points
at `raw_scpi` for anything not exposed.

---

# Tool count

**Phase 1**: ~18 tools. **Phase 2**: deferred backlog above (~15 more).

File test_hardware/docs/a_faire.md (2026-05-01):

## 1. write test code
Write a test firmware for the ESP32 pulsing for 1ms each of the GPIB pins

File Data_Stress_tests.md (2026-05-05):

# Test Specification: GPIB Stability Verification for Tektronix TDS784A

**Target Device:** Tektronix TDS784A (Firmware v4.1e)

**Interface:** AR-488 ESP32

**Objective:** Validate error-free bidirectional bulk data transfer to ensure the interface is safe for firmware flashing.

## 1. Environment Setup

- **Timeout:** Set a global GPIB timeout of 5000ms.

- **Termination:** Commands should end with `\\n`. GPIB EOI must be enabled.

## 2. Phase 1: Latency and Response Stability (The "Heartbeat")

- **Action:** Send `\*IDN?` in a loop 200 times.

- **Pass Criteria:**

  - 100% success rate (no timeouts).

  - Response must consistently start with `TEKTRONIX,TDS 784A...`.

- **Failure:** Any "Query Unterminated" or empty response indicates a handshake timing issue.

## 3. Phase 2: Bulk Read Stress Test (Curve Extraction)

- **Setup:** Set scope to CH1, Record Length to 15,000 points.

- **Action:**

  1. Send `DATA:SOURCE CH1; ENCDG RIBINARY; WIDTH 1;` (Sets up raw binary transfer).

  2. Send `CURVE?` and capture the resulting block.

  3. Loop this 20 times.

- **Pass Criteria:**

  1. Each `CURVE?` response should contain the standard Tek binary header (e.g., `\#515000...`).

  2. Total bytes received must exactly match the header's length field.

  3. No partial packets or checksum errors.

## 4. Phase 3: Bulk Write Stress Test (The "Flash Simulator")

- **Action:**

  1. Define a string of 1,024 random alphanumeric characters.

  2. Send `MESSAGE:SHOW "\<string\>"` to the scope.

  3. Immediately send `MESSAGE:STATE ON`.

  4. Repeat this 50 times, varying the string each time.

- **Pass Criteria:**

  1. The scope's display should update without hanging.

  2. The script must not encounter a "Serial Buffer Overflow" on the ESP32.

- **Validation:** If the script can push 1k chunks repeatedly without the AR-488 crashing, it can likely handle the firmware page-write cycle.

## 5. Phase 4: Screen Capture (Large Payload)

- **Setup:** Set Hardcopy format to `BMP` via scope menu.

- **Action:**

  1. Send `HARDCOPY START`.

  2. Read the raw stream until EOI is detected.

  3. Save the stream as a `.bmp` file.

- **Pass Criteria:**

  1. The resulting file must be a valid, viewable Windows Bitmap.

  2. No "shearing" or corruption in the image (indicates dropped bytes in the middle of a transfer).

## Technical Notes for the Python Agent:

- **Buffer Size:** Use a reading buffer of at least 10,240 bytes to handle the `CURVE?` data.

- **Error Handling:** Catch `SerialException` or `TimeoutError` and log the exact loop iteration where the failure occurred.

### A Final Tip on the "Write" Path

When your agent writes the script, have it pay special attention to the **GPIB EOI (End or Identify)** signal. During a firmware flash, the scope relies on EOI to know a data block is finished. If the AR-488 or the Python script doesn't handle EOI correctly, the scope may sit indefinitely waiting for more data, which is the most common cause of a failed flash.

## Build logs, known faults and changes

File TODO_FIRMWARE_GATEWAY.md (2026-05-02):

# AR-488-ESP32 firmware / gateway — issue log

Original report (2026-05-02) flagged three "firmware/gateway problems"
seen during the first hardware-in-the-loop smoke test of the
`tek-tds784a` MCP server. Investigation on 2026-05-03 with serial trace
points (Version v0.4-trace) showed only **one** of the three was an
actual firmware bug — the other two were misdiagnosed.

## 1. ~~First 2 bytes of some commands dropped~~ — NOT A FIRMWARE BUG

**Original symptom:** Errors like `unrecognized command - RIZONTAL:MAIN:SAMPLERATE?` (looks like "HO" was lost).

**Real cause:** The scope's error message buffer is showing the *parse-failure context*, not the bytes received. Trace confirmed the gateway sends the full command:

```
[trace ws] action=query len_after=27 cmd='HORIZONTAL:MAIN:SAMPLERATE?'
[trace sendData] len=27: 'HORIZONTAL:MAIN:SAMPLERATE?'
```

The TDS784A v4.1e simply **doesn't have** a `HORIZONTAL:MAIN:SAMPLERATE?` command. It also uses `HOLDOFF:TIME` not `HOLDOFF:VALUE`. Both are commands from newer Tek scope models.

**Fix:** in `host_software/request_gpib.py`:
- removed `("sample_rate_hz", "HORIZONTAL:MAIN:SAMPLERATE?")` from `_GLOBAL_META_QUERIES` — derive from `record_length / (10 * horizontal_scale_s)` if needed
- replaced `TRIGGER:MAIN:HOLDOFF:VALUE?` with `TRIGGER:MAIN:HOLDOFF:TIME?`

---

## 2. ~~`\0A` appended to HARDCOPY setup command~~ — NOT A FIRMWARE BUG

**Original symptom:** `Syntax error; invalid character data - HARDCOPY:PALETTE COLOR`.

**Real cause:** The TDS784A v4.1e's `HARDCOPY:PALETTE` only accepts `HARDCOPY` as a value on this firmware. `COLOR`, `MONOCHROME`, `INKSAVER`, `NORMAL` all return error 102 (probed). The image still rendered correctly because the scope kept its prior PALETTE setting after the rejected SET, but the error queue was being polluted.

**Fix:** in `host_software/mcp_server/server.py` `get_screen` — default palette to `HARDCOPY`, reject any other input with a helpful error.

---

## 3. `SET?` response truncated — REAL FIRMWARE BUG, FIXED IN v0.4

**Original symptom:** `setup_string` cut off at ~89 bytes mid-quoted-string (`...:APPM:TITL "Application`).

**Real cause:** The TDS784A's `SET?` response embeds `\n` as an internal line separator (e.g. inside `"Application\nMenu"`), with EOI asserted **only on the actual final byte**. The firmware's `query()` was breaking on `\n` OR EOI, so it terminated at the first internal newline:

```
[trace query recv] n=88, terminated=1, last_b=0x0A, last_eoi=0
```

`last_eoi=0` confirms the scope did NOT mean to terminate.

**Fix (`firmware/src/GpibBus.cpp`):** `query()` and `receive()` now break on EOI only — `\n` is just a data byte. Same logic applies to `receiveRaw`/`queryRaw` paths but those already only stop on EOI. Verified on v0.4 — `get_setup_state` now returns thousands of bytes including the multi-line `"Application\nMenu"` block, channel settings, trigger setup, math definitions, cursors. Hits the 4 KB buffer's `...truncated` suffix because the full SET? is even longer; for the complete dump, use the `binary_query` action which streams.

---

## Notes for future smoke tests

- Always query `gateway_firmware_version` first — confirms the running firmware matches what we think we built.
- TDS784A error messages truncate to a parse-context window. They show *where the parser stopped*, not what was received over the wire. Don't infer transmission corruption from them — use serial trace points on the gateway side instead.
- TDS784A SCPI uses the GPIB EOI line as the only reliable end-of-message marker. `\n` may appear mid-response.

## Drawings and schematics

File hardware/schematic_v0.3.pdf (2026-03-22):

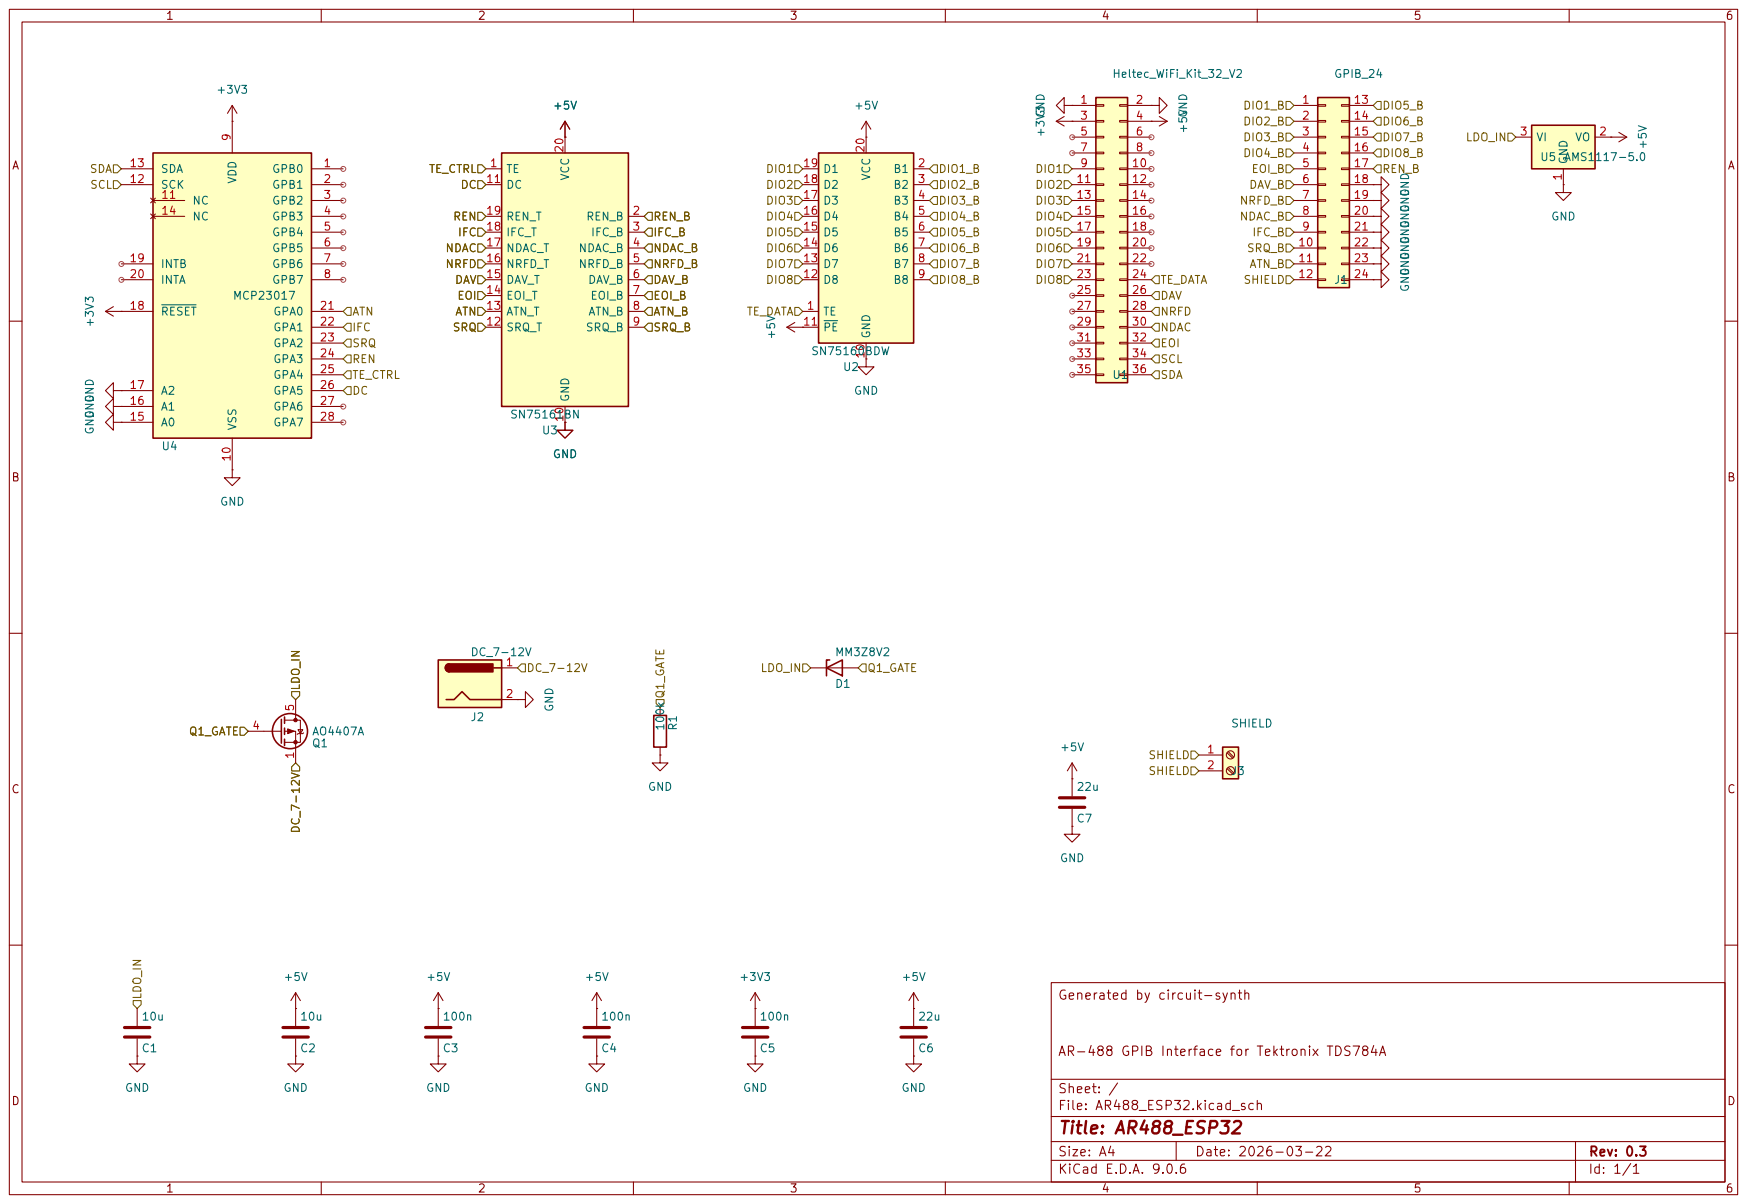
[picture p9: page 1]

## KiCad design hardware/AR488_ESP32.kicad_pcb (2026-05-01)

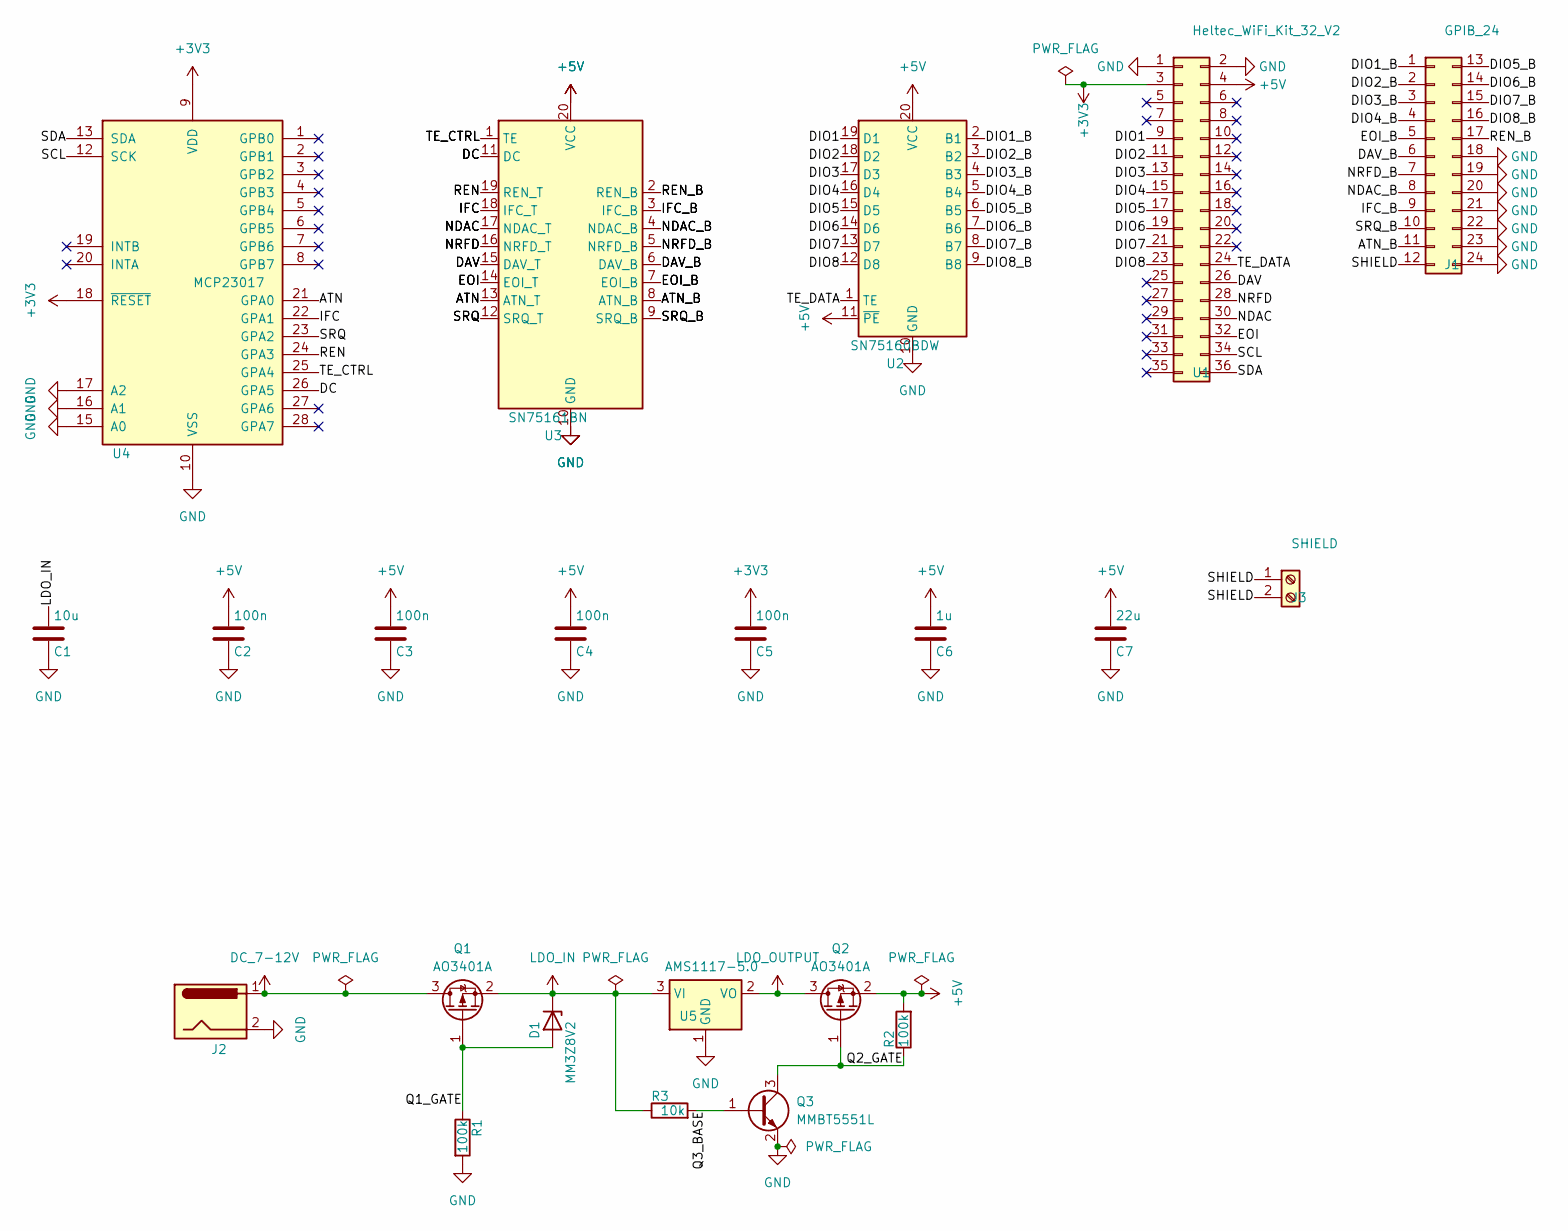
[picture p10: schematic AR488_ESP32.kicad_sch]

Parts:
C1: 10u; C_0603_1608Metric
C2, C3, C4, C5: 100n; C_0603_1608Metric
C6: 1u; C_0603_1608Metric
C7: 22u; C_0603_1608Metric
D1: MM3Z8V2; D_SOD-323
J1: GPIB_24; Centronics_24_GPIB_solder
J2: DC_7-12V; BarrelJack_Horizontal
J3: SHIELD; TerminalBlock_Phoenix_PT-1,5-2-5.0-H_1x02_P5.00mm_Horizontal
Q1, Q2: AO3401A; SOT-23
Q3: MMBT5551L; SOT-23
R1, R2: 100k; R_0603_1608Metric
R3: 10k; R_0603_1608Metric
U1: Heltec_WiFi_Kit_32_V2
U2: SN75160BDW; SOIC-20W_7.5x12.8mm_P1.27mm
U3: SN75161BN; DIP-20_W7.62mm
U4: MCP23017; SOIC-28W_7.5x17.9mm_P1.27mm
U5: AMS1117-5.0; SOT-223-3_TabPin2

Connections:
+3V3: C5.1, U1.3, U4.9 (VDD), U4.18 (~RESET)
+5V: C2.1, C3.1, C4.1, C6.1, C7.1, Q2.2 (S), R2.2, U1.4, U2.11 (~PE), U2.20 (VCC), U3.20 (VCC)
/ATN: U3.13 (ATN_T), U4.21 (GPA0)
/ATN_B: J1.11, U3.8 (ATN_B)
/DAV: U1.26, U3.15 (DAV_T)
/DAV_B: J1.6, U3.6 (DAV_B)
/DC: U3.11 (DC), U4.26 (GPA5)
/DIO1: U1.9, U2.19 (D1)
/DIO1_B: J1.1, U2.2 (B1)
/DIO2: U1.11, U2.18 (D2)
/DIO2_B: J1.2, U2.3 (B2)
/DIO3: U1.13, U2.17 (D3)
/DIO3_B: J1.3, U2.4 (B3)
/DIO4: U1.15, U2.16 (D4)
/DIO4_B: J1.4, U2.5 (B4)
/DIO5: U1.17, U2.15 (D5)
/DIO5_B: J1.13, U2.6 (B5)
/DIO6: U1.19, U2.14 (D6)
/DIO6_B: J1.14, U2.7 (B6)
/DIO7: U1.21, U2.13 (D7)
/DIO7_B: J1.15, U2.8 (B7)
/DIO8: U1.23, U2.12 (D8)
/DIO8_B: J1.16, U2.9 (B8)
/EOI: U1.32, U3.14 (EOI_T)
/EOI_B: J1.5, U3.7 (EOI_B)
/IFC: U3.18 (IFC_T), U4.22 (GPA1)
/IFC_B: J1.9, U3.3 (IFC_B)
/NDAC: U1.30, U3.17 (NDAC_T)
/NDAC_B: J1.8, U3.4 (NDAC_B)
/NRFD: U1.28, U3.16 (NRFD_T)
/NRFD_B: J1.7, U3.5 (NRFD_B)
/Q1_GATE: D1.2 (A), Q1.1 (G), R1.1
/Q2_GATE: Q2.1 (G), Q3.3 (C), R2.1
/Q3_BASE: Q3.1 (B), R3.2
/REN: U3.19 (REN_T), U4.24 (GPA3)
/REN_B: J1.17, U3.2 (REN_B)
/SCL: U1.34, U4.12 (SCK)
/SDA: U1.36, U4.13 (SDA)
/SHIELD: J1.12, J3.1, J3.2
/SRQ: U3.12 (SRQ_T), U4.23 (GPA2)
/SRQ_B: J1.10, U3.9 (SRQ_B)
/TE_CTRL: U3.1 (TE), U4.25 (GPA4)
/TE_DATA: U1.24, U2.1 (TE)
DC_7-12V: J2.1, Q1.3 (D)
GND: C1.2, C2.2, C3.2, C4.2, C5.2, C6.2, C7.2, J1.18, J1.19, J1.20, J1.21, J1.22, J1.23, J1.24, J2.2, Q3.2 (E), R1.2, U1.1, U1.2, U2.10 (GND), U3.10 (GND), U4.10 (VSS), U4.15 (A0), U4.16 (A1), U4.17 (A2), U5.1 (GND)
LDO_IN: C1.1, D1.1 (K), Q1.2 (S), R3.1, U5.3 (VI)
LDO_OUTPUT: Q2.3 (D), U5.2 (VO)

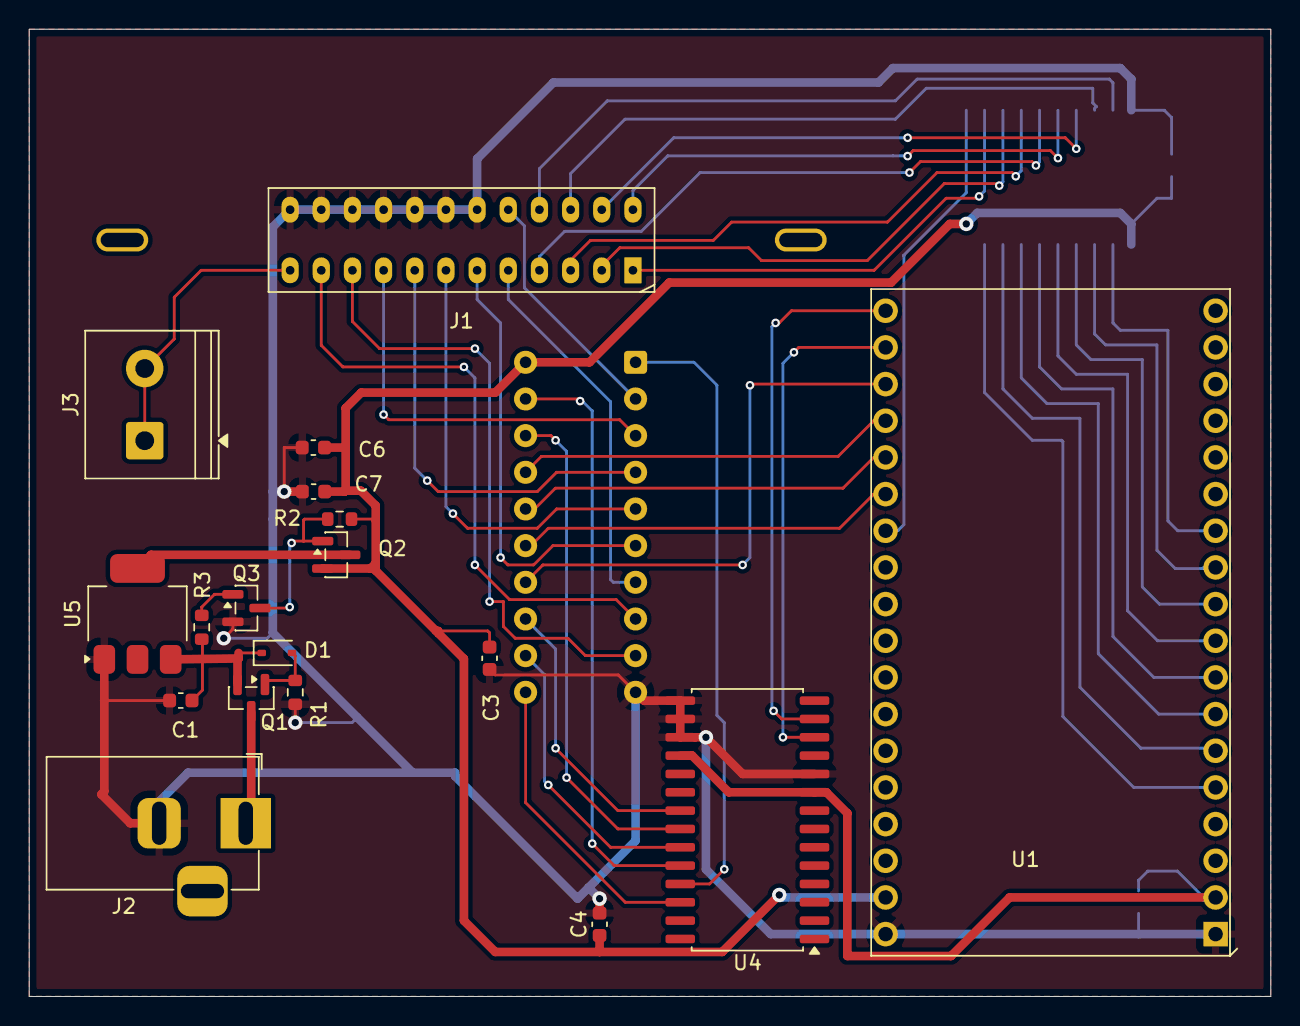
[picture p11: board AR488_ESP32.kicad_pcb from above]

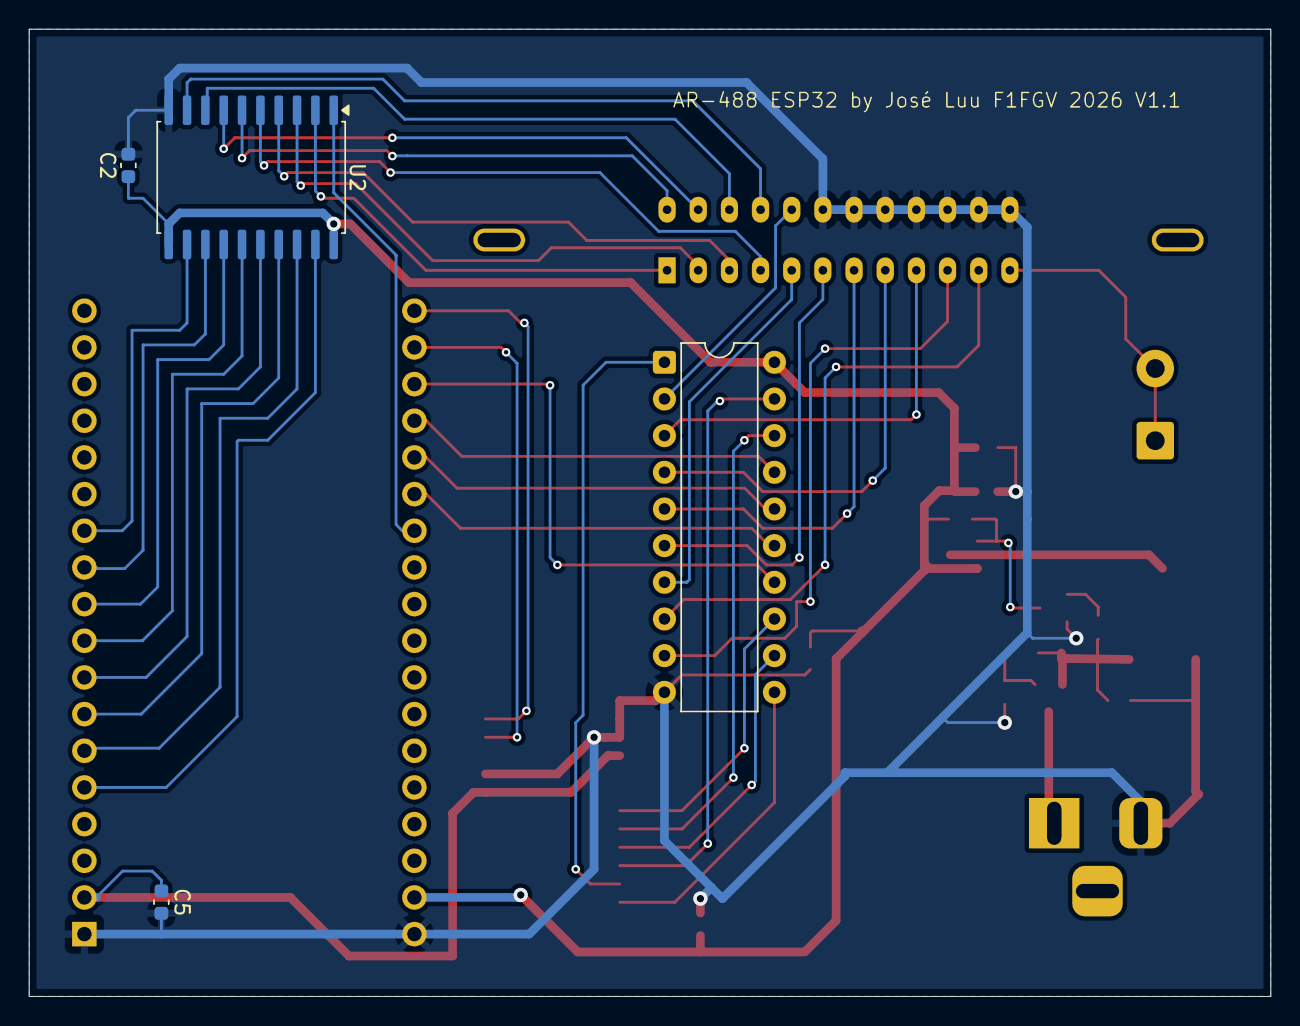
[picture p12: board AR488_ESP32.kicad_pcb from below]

Board: 2 copper layers, 86.0 x 67.0 mm, 22 parts (4 on the bottom side), 47 nets.

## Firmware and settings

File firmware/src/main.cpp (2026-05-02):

// AR-488-ESP32 firmware — Phase 2.
//
// Boot flow:
//   1. OLED + GpibBus HAL up (Core 1).
//   2. WiFi STA join using credentials from network_creds.h.
//   3. AsyncWebServer + AsyncWebSocket on /ws (Core 0 via AsyncTCP).
//   4. GpibWorker FreeRTOS task pinned to Core 1 services the WS queue.
//   5. GPIB probe loop: detect device at the persisted default addr,
//      retry forever, restart probe if a `set_default_addr` request
//      changes the target mid-search.
//
// JSON request:
//   { "request_id": "1", "action": "query"|"write"|"read",
//     "command": "*IDN?", "addr": 1, "timeout_ms": 2000 }
// JSON response:
//   { "request_id": "1", "ok": true, "data": "TEKTRONIX,..." }

#include <Arduino.h>
#include <WiFi.h>

#include "Display.h"
#include "GpibBus.h"
#include "GpibWorker.h"
#include "Version.h"
#include "WsServer.h"

#include "../network_creds.h"                   // ssid, password

static constexpr uint8_t SCOPE_ADDR_FALLBACK = 1;       // when NVS is unset

static Display    g_display;
static GpibBus    g_gpib;
static GpibWorker g_worker;
static WsServer   g_ws;

// Re-reads g_worker.defaultAddr() each pass so a `set_default_addr`
// request that arrives mid-probe immediately retargets us.
static void waitForScope() {
    uint8_t target = g_worker.defaultAddr();
    g_display.log("Probe @addr %u", target);
    Serial.printf("[gpib] probing @addr %u\n", target);
    int attempts = 0;

    for (;;) {
        uint8_t cur = g_worker.defaultAddr();
        if (cur != target) {
            target = cur;
            attempts = 0;
            g_display.log("Probe @addr %u", target);
            Serial.printf("[gpib] retarget @addr %u\n", target);
        }
        if (g_gpib.detectDevice(target, /*timeoutMs=*/200)) break;

        ++attempts;
        if (attempts == 1) g_display.log("No device, retry 1");
        else               g_display.replaceLast("No device, retry %d", attempts);
        Serial.printf("[gpib] no device @%u, retry %d\n", target, attempts);

        // 2 s wait, polled every 100 ms so an addr change unblocks us
        // without waiting for the full retry interval.
        for (int i = 0; i < 20; ++i) {
            delay(100);
            if (g_worker.defaultAddr() != target) break;
        }
    }
    g_display.log("Device OK.");

    target = g_worker.defaultAddr();
    char reply[128];
    int n = g_gpib.query(target, "*IDN?\n", reply, sizeof(reply), 2000);
    if (n <= 0) { g_display.log("*IDN? timeout"); return; }
    while (n > 0 && (reply[n - 1] == '\n' || reply[n - 1] == '\r')) reply[--n] = 0;
    Serial.printf("[gpib] *IDN? -> '%s'\n", reply);

    char chunk[22];
    int pos = 0;
    while (pos < n && pos < 42) {
        int take = min<int>(21, n - pos);
        memcpy(chunk, &reply[pos], take);
        chunk[take] = 0;
        g_display.log("%s", chunk);
        pos += take;
    }
}

static bool connectWiFi(uint32_t timeoutMs) {
    WiFi.mode(WIFI_STA);
    WiFi.setSleep(false);
    WiFi.begin(ssid, password);
    Serial.printf("[wifi] joining '%s'...\n", ssid);
    g_display.log("WiFi: %.16s", ssid);

    uint32_t t0 = millis();
    while (WiFi.status() != WL_CONNECTED) {
        if (millis() - t0 > timeoutMs) return false;
        delay(200);
    }
    return true;
}

void setup() {
    Serial.begin(115200);
    delay(150);
    Serial.println();
    Serial.printf("AR-488-ESP32 firmware v%s\n", AR488_FW_VERSION);

    g_display.begin();
    g_display.title("AR-488 v" AR488_FW_VERSION);
    g_display.log("Booting...");

    if (!g_gpib.begin()) {
        Serial.println("[gpib] begin failed");
        g_display.log("MCP23017 fail");
        return;
    }
    if (!g_gpib.controllerInit()) {
        Serial.println("[gpib] ctrl init failed");
        g_display.log("CtrlInit fail");
        return;
    }

    // Bring WiFi + WS up first so the gateway is reachable while we
    // probe for the GPIB device. A `set_default_addr` request that
    // arrives during the probe will retarget us promptly.
    if (!connectWiFi(20000)) {
        Serial.println("[wifi] timeout");
        g_display.log("WiFi timeout");
        return;
    }
    IPAddress ip = WiFi.localIP();
    Serial.printf("[wifi] connected: %s\n", ip.toString().c_str());
    g_display.log("IP %s", ip.toString().c_str());

    uint8_t startAddr = GpibWorker::loadPersistedAddr(SCOPE_ADDR_FALLBACK);
    Serial.printf("[gpib] default addr = %u (loaded from NVS)\n", startAddr);

    if (!g_worker.begin(&g_gpib, g_ws.ws(), &g_display, startAddr)) {
        Serial.println("[worker] start failed");
        g_display.log("Worker fail");
        return;
    }
    g_ws.begin(&g_worker);
    Serial.println("[ws] listening on ws://*/ws");
    g_display.log("WS ready :80/ws");

    waitForScope();
}

void loop() {
    static uint32_t lastClients = 0xFFFFFFFF;
    static uint32_t lastTick = 0;
    if (millis() - lastTick > 1000) {
        lastTick = millis();
        g_ws.ws()->cleanupClients();
        size_t n = g_ws.clientCount();
        if (n != lastClients) {
            lastClients = n;
            g_display.log("Clients: %u", (unsigned)n);
        }
    }
    delay(50);
}

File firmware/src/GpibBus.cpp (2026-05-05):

#include "GpibBus.h"

#include <Wire.h>
#include <string.h>

// --------------------------------------------------------------------------
// Pinout — must match firmware/HARDWARE.md.

static constexpr uint8_t I2C_SDA_PIN   = 21;
static constexpr uint8_t I2C_SCL_PIN   = 22;
static constexpr uint8_t MCP23017_ADDR = 0x20;

static constexpr uint8_t MCP_IODIRA = 0x00;
static constexpr uint8_t MCP_IODIRB = 0x01;
static constexpr uint8_t MCP_OLATA  = 0x14;
static constexpr uint8_t MCP_OLATB  = 0x15;

static constexpr uint8_t MCP_BIT_ATN     = 0;
static constexpr uint8_t MCP_BIT_IFC     = 1;
static constexpr uint8_t MCP_BIT_SRQ     = 2;
static constexpr uint8_t MCP_BIT_REN     = 3;
static constexpr uint8_t MCP_BIT_TE_CTRL = 4;
static constexpr uint8_t MCP_BIT_DC      = 5;

// 8-bit GPIB data bus, indexed by DIO1..DIO8.
static constexpr uint8_t kDioPin[8] = {
    13, 12, 14, 27, 26, 25, 33, 32
};

static constexpr uint8_t GPIO_DAV     = 5;
static constexpr uint8_t GPIO_NRFD    = 18;
static constexpr uint8_t GPIO_NDAC    = 23;
static constexpr uint8_t GPIO_EOI     = 19;
static constexpr uint8_t GPIO_TE_DATA = 17;

// --------------------------------------------------------------------------
// MCP23017 helpers.

bool GpibBus::mcpWrite(uint8_t reg, uint8_t value) {
    Wire.beginTransmission(MCP23017_ADDR);
    Wire.write(reg);
    Wire.write(value);
    return Wire.endTransmission() == 0;
}

bool GpibBus::mcpSetOlatA(uint8_t v) {
    mcpOlatA_ = v;
    return mcpWrite(MCP_OLATA, v);
}

bool GpibBus::mcpSetBitA(uint8_t bit, bool high) {
    uint8_t v = mcpOlatA_;
    if (high) v |= (1u << bit);
    else      v &= ~(1u << bit);
    return mcpSetOlatA(v);
}

// --------------------------------------------------------------------------
// Data bus.

void GpibBus::setDataDir(bool output) {
    for (uint8_t i = 0; i < 8; ++i) {
        if (output) {
            pinMode(kDioPin[i], OUTPUT);
            digitalWrite(kDioPin[i], HIGH);     // released
        } else {
            pinMode(kDioPin[i], INPUT);
        }
    }
}

void GpibBus::writeData(uint8_t b) {
    // Bus is negative-true; transceiver is non-inverting -> invert in SW.
    uint8_t inv = ~b;
    for (uint8_t i = 0; i < 8; ++i) {
        digitalWrite(kDioPin[i], (inv >> i) & 0x01 ? HIGH : LOW);
    }
}

uint8_t GpibBus::readData() {
    uint8_t v = 0;
    for (uint8_t i = 0; i < 8; ++i) {
        if (digitalRead(kDioPin[i])) v |= (1u << i);
    }
    return ~v;
}

// --------------------------------------------------------------------------
// Direction control.

void GpibBus::setTalker() {
    if (talker_) return;

    // Drive handshake outputs to released BEFORE flipping TE_CTRL, so we
    // don't briefly assert DAV/EOI on the bus when SN75161B switches.
    digitalWrite(GPIO_DAV, HIGH);
    digitalWrite(GPIO_EOI, HIGH);
    pinMode(GPIO_DAV, OUTPUT);
    pinMode(GPIO_EOI, OUTPUT);
    pinMode(GPIO_NRFD, INPUT);
    pinMode(GPIO_NDAC, INPUT);

    digitalWrite(GPIO_TE_DATA, HIGH);           // SN75160B Talk (DIO out)
    setDataDir(true);

    mcpSetBitA(MCP_BIT_TE_CTRL, true);          // SN75161B handshake Talk
    delayMicroseconds(2);
    talker_ = true;
}

void GpibBus::setListener() {
    if (!talker_) return;

    // Pre-load the handshake outputs we'll be driving as listener.
    digitalWrite(GPIO_NRFD, LOW);               // not ready
    digitalWrite(GPIO_NDAC, LOW);               // not accepted
    pinMode(GPIO_NRFD, OUTPUT);
    pinMode(GPIO_NDAC, OUTPUT);
    pinMode(GPIO_DAV, INPUT);
    pinMode(GPIO_EOI, INPUT);

    digitalWrite(GPIO_TE_DATA, LOW);            // SN75160B Listen (DIO in)
    setDataDir(false);

    mcpSetBitA(MCP_BIT_TE_CTRL, false);         // SN75161B handshake Listen
    delayMicroseconds(2);
    talker_ = false;
}

void GpibBus::assertATN()    { mcpSetBitA(MCP_BIT_ATN,  false); }
void GpibBus::releaseATN()   { mcpSetBitA(MCP_BIT_ATN,  true);  }
void GpibBus::assertIFC()    { mcpSetBitA(MCP_BIT_IFC,  false); }
void GpibBus::releaseIFC()   { mcpSetBitA(MCP_BIT_IFC,  true);  }
void GpibBus::assertREN()    { mcpSetBitA(MCP_BIT_REN,  false); }
void GpibBus::releaseREN()   { mcpSetBitA(MCP_BIT_REN,  true);  }

// --------------------------------------------------------------------------
// Initialisation.

bool GpibBus::begin() {
    // Boot-strap safety: GPIO12 (DIO2) must be LOW. Done first so the
    // SN75160B can't back-drive it before we get TE_DATA defined.
    pinMode(12, OUTPUT);
    digitalWrite(12, LOW);

    pinMode(GPIO_TE_DATA, OUTPUT);
    digitalWrite(GPIO_TE_DATA, HIGH);           // SN75160B Talk

    // Default release state for the direct handshake outputs.
    pinMode(GPIO_DAV, OUTPUT);  digitalWrite(GPIO_DAV, HIGH);
    pinMode(GPIO_EOI, OUTPUT);  digitalWrite(GPIO_EOI, HIGH);
    pinMode(GPIO_NRFD, INPUT);
    pinMode(GPIO_NDAC, INPUT);
    setDataDir(true);                           // DIO outputs, released (HIGH)
    talker_ = true;

    Wire.begin(I2C_SDA_PIN, I2C_SCL_PIN);
    Wire.setClock(400000);

    // GPIOA = outputs (used). GPIOB = outputs forced LOW (unused on board).
    bool ok = mcpWrite(MCP_OLATB, 0x00)
           && mcpWrite(MCP_IODIRB, 0x00)
           && mcpWrite(MCP_IODIRA, 0x00);
    if (!ok) return false;

    // ATN/IFC/SRQ/REN released (=HIGH=1), TE_CTRL=H (Talk), DC=L (controller).
    // bits 0..4 = 1, bit 5 = 0  ->  0x1F.
    if (!mcpSetOlatA(0x1F)) return false;

    mtx_ = xSemaphoreCreateMutex();
    return mtx_ != nullptr;
}

bool GpibBus::lock(uint32_t timeoutMs) {
    if (!mtx_) return false;
    return xSemaphoreTake(mtx_, pdMS_TO_TICKS(timeoutMs)) == pdTRUE;
}

void GpibBus::unlock() {
    if (mtx_) xSemaphoreGive(mtx_);
}

bool GpibBus::controllerInit() {
    if (!lock()) return false;
    setTalker();
    releaseATN();
    assertIFC();
    delay(1);                                    // IFC must be >100us; 1ms is generous
    releaseIFC();
    assertREN();
    delay(1);
    unlock();
    return true;
}

// --------------------------------------------------------------------------
// Byte-level handshake.
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

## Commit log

2026-03-22 feat: AR-488-ESP32 GPIB interface schematic v0.2
    Initial project with full schematic design:
    - ESP32 (Heltec WiFi Kit 32 V2) + SN75160BDW/SN75161BN GPIB transceivers
    - MCP23017 I2C GPIO expander for slow management signals
    - AO4407A P-FET reverse polarity protection + AMS1117-5.0 LDO
    - MM3Z8V2 Zener diode gate clamp on Q1
    - GPIB Centronics 24-pin connector (top-bottom pin numbering)
    - Shield pin routed to J3 screw terminal (not GND)
    - Custom KiCad symbols (SN75161BN, AO4407A) and footprints
    [AR488_ESP32.kicad_sch]
2026-03-22 chore: add circuit-synth as git submodule from joseluu/circuit-synth
    Tracks the fix/windows-utf8-file-write branch.
    main.py (circuit design) has local modifications not yet pushed.
2026-03-22 feat: v0.3 — remove annotation, force A4, C1 to 0603
    - Remove docstring text box annotation from schematic (comments=False)
    - Force A4 paper size (components now fit with 3 rows)
    - Change C1 (LDO input cap) from 0805 to 0603 package
    - Bump revision to 0.3
    [AR488_ESP32.kicad_sch]
2026-03-22 docs: v0.4 — rewrite README with project intent, workflow, electrical architecture
    [AR488_ESP32.kicad_sch]
2026-03-22 docs: add schematic PDF export (v0.3)
2026-04-11 feat: v0.5 — switch Q1 to AO3401A, fix ERC to 0 errors
    - Replace Q1 AO4407A (SOIC-8) with AO3401A (SOT-23) for simpler RPP
    - Convert all hierarchical labels to net labels (fix 30+ ERC errors)
    - Add no-connect flags on unused U4 (MCP23017) and U1 (ESP32) pins
    - Add PWR_FLAG symbols on +5V, +3V3, GND, LDO_IN nets
    - Add solder-friendly Centronics footprint variant (0.6mm drill, 4.2mm row spacing)
    - Move custom libs from libs/ to AR488_ESP32/libs/ with fp/sym-lib-table
    - Add PCB board file, net classes (Power: 0.6mm track), edge cuts
    - Update CLAUDE.md with MCP server guidance and project conventions
    [AR488_ESP32.kicad_pcb, AR488_ESP32.kicad_sch]
2026-04-11 feat: update GPIB solder footprint — plated oblong mounting holes, 55mm outline
    - Mounting holes: plated through-hole oval (3x1mm drill, 3.6x1.6mm pad)
    with pad numbers 25/26 for OUT_SHIELD net connection
    - Courtyard width extended from 52.3mm to 55mm
    - PCB and schematic updates from KiCad editor (PWR_FLAGs, F8 sync)
    [AR488_ESP32.kicad_pcb, AR488_ESP32.kicad_sch]
2026-04-11 feat: PCB layout progress — component placement and editor updates
    [AR488_ESP32.kicad_pcb]
2026-04-11 chore: KiCad editor state updates
    [AR488_ESP32.kicad_pcb, AR488_ESP32.kicad_sch]
2026-04-11 feat: add Elecrow manufacturing Gerbers (v1)
    Export Gerber and drill files for Elecrow PCB fabrication.
    [AR488_ESP32-B_Cu.gbr, AR488_ESP32-B_Mask.gbr, AR488_ESP32-B_Paste.gbr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]
2026-04-11 feat: add 3D model for Centronics 24-pin GPIB connector
    VRML model with blue plastic housing, metal shield, pin stubs,
    and mounting ears. Linked to solder variant footprint.
2026-04-11 feat: add 3D model for Heltec WiFi Kit 32 V2 (U1)
    White PCB with OLED display, ESP32 shield, USB connector,
    pin headers, and "Heltec WiFi Kit V2" text label.
    Document VRML scaling convention (scale ~394) in CLAUDE.md.
2026-04-11 feat: v1.1 — PCB and schematic updates, Elecrow manufacturing v1.1
    [AR488_ESP32-B_Cu.gbr, AR488_ESP32-B_Mask.gbr, AR488_ESP32-B_Paste.gbr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]
2026-04-26 docs: add board photo to README, ignore uv.lock
2026-05-01 add more details
    [AR488_ESP32.kicad_pcb]
2026-05-02 reorder directories, improve firmware and host software, validate color screen copies
    [AR488_ESP32-B_Cu.gbr, AR488_ESP32-B_Mask.gbr, AR488_ESP32-B_Paste.gbr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]
